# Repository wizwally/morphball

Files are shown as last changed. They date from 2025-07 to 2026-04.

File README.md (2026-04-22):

# 🔮 Metroid Morph Ball

3D printed Metroid Morph Ball action figure with LED animations controlled by ESP32 and IMU motion sensor.





[🇮🇹 Versione Italiana](README.md) | 🇬🇧 English Version

## 📋 Table of Contents

- [Overview](#overview)
- [Features](#features)
- [Hardware](#hardware)
- [Software](#software)
- [Installation](#installation)
- [Usage](#usage)
- [Future Development](#future-development)
- [Contributing](#contributing)
- [License](#license)

## 🎮 Overview

This project recreates the legendary **Morph Ball** from the Metroid series as an interactive 3D printed action figure. The sphere illuminates with 32 programmable WS2812B LEDs and responds to movement thanks to an IMU sensor, automatically entering deep sleep when stationary to save battery.

### Two Available Versions

The project offers two complete implementations:

1. **MicroPython** (`/ESP32` + `/MG24`) - Original standalone version
2. **ESPHome** (`/ESPHome`) - Full Home Assistant integration

## ✨ Features

- 🎨 **32 RGB WS2812B LEDs** with customizable animations
- 🏃 **Motion detection** via LSM6DS3 accelerometer
- 💤 **Automatic deep sleep** for energy saving
- 🔋 **Wake on movement** for instant activation
- 🏠 **Home Assistant integration** (ESPHome version)
- 📱 **WiFi control** with effect selection and configuration
- 🎯 **Custom LED groups** that reproduce the Metroid aesthetic
- ⚡ **Dual-MCU architecture** (ESP32-S3 + MG24) for optimized power consumption

## 🔧 Hardware

### Why Dual-MCU Architecture?

This project uses **two microcontrollers** instead of one for strategic reasons:

1. **🔋 Optimized Power Management**
   - MG24 runs in ultra-low power mode continuously monitoring the IMU
   - ESP32 can deep sleep (~10µA) while MG24 acts as motion "sentinel"
   - Wake-on-motion with minimal latency and maximum battery life

2. **📡 ESP32-S3 Tiny Has No Integrated IMU**
   - The compact ESP32-S3 Tiny form factor doesn't include motion sensors
   - XIAO MG24 has LSM6DS3 accelerometer already integrated on-board
   - No need for external IMU breakout boards and extra wiring

3. **⚡ Task Separation & Real-Time Performance**
   - **MG24**: Dedicated to real-time IMU polling (20Hz) and motion detection
   - **ESP32**: Handles LED animations, WiFi, Home Assistant integration
   - No resource contention - each MCU does what it does best

4. **🎯 Continuous Monitoring Without Impact**
   - MG24 polls IMU continuously at 20Hz without affecting ESP32 performance
   - LED animations run smoothly on ESP32 without IMU polling overhead
   - Clean separation of concerns in the codebase

**Alternative single-MCU approach drawbacks:**
- ❌ ESP32 polling IMU = high power consumption (no true deep sleep)
- ❌ Wake-on-timer = high latency (100-500ms) and still wastes power
- ❌ External IMU module = more complex wiring, larger footprint

**Dual-MCU benefits:**
- ✅ Best-in-class power efficiency (~100µA average in standby)
- ✅ Instant wake on motion (<50ms latency)
- ✅ Modular architecture (can upgrade/swap MCUs independently)
- ✅ Both MCUs in same XIAO form factor (stack back-to-back)

### Main Components

| Component | Model | Quantity | Est. Price | Link/Notes |
|---|---|---|---|---|
| **ESP32-S3 Tiny** | Dual-core, WiFi, BLE | 1 | €8-12 | Ideal small form factor |
| **Seeed XIAO MG24** | ARM Cortex-M33, integrated LSM6DS3 | 1 | €10-15 | Includes on-board IMU |
| **LED Strip WS2812B** | 5V, IP30, 60 LED/m | 32 LED (~53cm) | €5-8 | Cuttable every LED |
| **LiPo Battery** | 3.7V, 500-1000mAh | 1 | €8-12 | Size TBD |
| **Charging Module** | TP4056 or similar | 1 | €2-3 | With protection |
| **ON/OFF Switch** | Slide switch 3 pin | 1 | €0.50 | Miniature |
| **JST Connectors** | 2.54mm pitch | Various | €2-3 | For modular connections |
| **Wires** | AWG 22-26, silicone | 1m | €2-3 | Red/Black/Data |
| **Heat shrink** | Heat shrink tubing | 10cm | €1 | Various sizes |

### Connection Diagram

```
ESP32-S3 Tiny          MG24 (XIAO)         LED Strip
┌─────────────┐       ┌──────────┐        ┌─────────┐
│             │       │          │        │         │
│ GPIO18 ─────┼───────┼──────────┼────────┤ DIN     │
│             │       │          │        │         │
│ GPIO8  ◄────┼───────┤ D4 (OUT) │        │         │
│ (MOTION IN) │       │          │        │         │
│             │       │          │        │         │
│ GPIO7  ─────┼───────► D5 (IN)  │        │         │
│ (ALIVE OUT) │       │ LSM6DS3  │        │         │
│             │       │   IMU    │        │         │
│ 3V3    ─────┼───────┤ 3V3      │        │         │
│ GND    ─────┼───────┤ GND      ├────────┤ GND     │
│             │       │          │        │         │
└─────────────┘       └──────────┘        │ +5V ◄───┤ Battery
                                          └─────────┘
```

### Pin Details

**ESP32-S3 Tiny:**
- `GPIO18`: DIN of WS2812B LED strip
- `GPIO8`: Input from MG24 (HIGH when motion detected)
- `GPIO7`: Output to MG24 (HIGH when animations active)

**MG24 (XIAO):**
- `D4`: Output to ESP32 (pulse on movement)
- `D5`: Input from ESP32 (animation status)
- `D6`: Serial1 TX → ESP32 RX (future UART, structured IMU messages)
- `D7`: Serial1 RX ← ESP32 TX (future UART, configuration commands)
- `D11/D12`: SAMD11 debug bridge — **DO NOT TOUCH**
- `SDA/SCL`: I2C for LSM6DS3 (internal)

### LED Layout

The 32 LEDs are organized in 3 groups to recreate the Metroid aesthetic:

- **Group 0** (6 LEDs): Core grills - Aqua green `(0, 230, 100)`
  - Positions: `[0, 19, 20, 25, 26, 31]`
  
- **Group 1** (12 LEDs): Inner ring - Bright green `(0, 255, 30)`
  - Positions: `[1, 2, 17, 18, 21, 22, 23, 24, 27, 28, 29, 30]`
  
- **Group 2** (14 LEDs): Outer ring - Bright green `(0, 255, 30)`
  - Positions: `[3-16]`

## 💾 Software

### Repository Structure

```
morphball/
├── 3D model/                # 3D printable model
│   └── MorphBall.3mf
├── ESP32/                   # MicroPython standalone version
│   ├── main.py             # Entry point
│   ├── ledstrip.py         # LED management
│   └── animations/         # LED effects
│       ├── base.py
│       ├── pulse.py
│       ├── rotation.py
│       └── static.py
├── MG24/                    # Motion sensor code
│   └── mg24_imu.ino        # Arduino sketch for IMU
├── ESPHome/                 # Home Assistant version
│   ├── morphball.yaml      # ESPHome config
│   ├── README.md           # Setup guide
│   ├── lovelace-card.yaml  # HA Dashboard
│   └── secrets.yaml.example
└── docs/                    # Documentation
    ├── en/                  # English docs
    └── [IT docs]            # Italian docs
```

### MicroPython Version

**Features:**
- Standalone, doesn't require WiFi connection
- Automatic pulse animation
- Sleep after 20 seconds of inactivity
- Deep sleep after additional 20 seconds in standby

**Main files:**
- `main.py`: Main loop, thread management, sleep management
- `ledstrip.py`: Class for WS2812B control with groups
- `animations/`: Modules with different LED effects

### ESPHome Version

**Features:**
- Native Home Assistant integration
- 11 selectable LED effects
- Timeout configuration via dashboard
- OTA updates
- Complete diagnostics (WiFi, uptime, IP)

**Advantages:**
- No mobile app needed
- Configuration via web interface
- HA automations available
- Synchronization with other devices

See [ESPHome/README.md](ESPHome/README.md) for complete details.

## 🚀 Installation

### Software Requirements

**For MicroPython version:**
- Python 3.7+
- `esptool` for flashing
- `mpremote` or `ampy` for file upload

**For ESPHome version:**
- ESPHome CLI or Home Assistant addon
- Home Assistant (obviously!)

### MicroPython Version Setup

1. **Flash MicroPython on ESP32-S3:**
```bash
esptool.py --chip esp32s3 --port /dev/ttyUSB0 erase_flash
esptool.py --chip esp32s3 --port /dev/ttyUSB0 write_flash -z 0x0 esp32s3-micropython.bin
```

2. **Upload code:**
```bash
cd ESP32
mpremote connect /dev/ttyUSB0 cp -r . :
```

3. **Flash MG24:**
```bash
# Use Arduino IDE
# Board: Seeed XIAO MG24
# Upload: MG24/mg24_imu.ino
```

### ESPHome Version Setup

See complete documentation in [ESPHome/README.md](ESPHome/README.md)

**Quick start:**
```bash
cd ESPHome
cp secrets.yaml.example secrets.yaml
# Edit secrets.yaml with your credentials
esphome run morphball.yaml
```

## 🎯 Usage

### MicroPython Version

The Morph Ball activates automatically:
1. **Motion detected** → LEDs turn on with pulse effect
2. **20s of inactivity** → Enters standby (only core grills lit)
3. **Another 20s stationary** → Complete deep sleep
4. **New movement** → Automatic wake and reactivation

### ESPHome Version

**Home Assistant Dashboard:**
1. Turn LEDs on/off
2. Select effect from dropdown
3. Adjust sleep timeout with slider
4. Enable/disable deep sleep mode
5. Monitor motion status and diagnostics

**Example automations:**

```yaml
# Activate Rainbow at sunset
automation:
  - alias: "Morphball Rainbow Sunset"
    trigger:
      platform: sun
      event: sunset
    action:
      - service: select.select_option
        target:
          entity_id: select.metroid_morph_ball_effect
        data:
          option: "Rainbow"
```

## 🔮 Future Development

### Roadmap

- [ ] **Gesture recognition** - Shake, roll, tilt trigger different effects
- [ ] **Battery monitoring** - Charge level indicator
- [ ] **Game mode** - Interactive mini-games
- [ ] **Multi-ball sync** - Multiple Morph Balls communicating
- [ ] **Audio feedback** - Speaker for Metroid sounds
- [ ] **Charging dock** - Wireless charging base
- [ ] **Mobile app** - For standalone MicroPython version
- [ ] **Audio-reactive effects** - Music synchronization

### Contribution Ideas

- New LED animations
- Power consumption optimization
- 3D model improvements
- Porting to other microcontrollers
- Integration with other smart home systems (Alexa, Google Home)

## 🤝 Contributing

Contributions welcome! Here's how:

1. **Fork** the repository
2. Create a **branch** for your feature (`git checkout -b feature/AmazingFeature`)
3. **Commit** your changes (`git commit -m 'Add some AmazingFeature'`)
4. **Push** to the branch (`git push origin feature/AmazingFeature`)
5. Open a **Pull Request**

### Guidelines

- Comment code (English preferred for international collaboration)
- Test changes before committing
- Update documentation if necessary
- Follow existing code style

See [CONTRIBUTING.md](CONTRIBUTING.md) for detailed guidelines.

## 📄 License

This project is released under **GPL-3.0 License**. See [LICENSE](LICENSE) for details.

## 🙏 Acknowledgments

- **Nintendo/Retro Studios** for Metroid inspiration
- **ESPHome Community** for the fantastic framework
- **Home Assistant** for the home automation platform
- **Seeed Studio** for XIAO MG24
- All contributors who will improve this project!

## 📞 Contact

**Gualtiero Saderis** - [@wizwally](https://github.com/wizwally)

Project Link: [https://github.com/wizwally/morphball](https://github.com/wizwally/morphball)

---

## 📚 Documentation

- **English:**
  - [Hardware Guide](docs/en/HARDWARE.md)
  - [Software Architecture](docs/en/SOFTWARE.md)
  - [Build Tutorial](docs/en/TUTORIAL.md)
  - [Contributing Guide](docs/en/CONTRIBUTING.md)

- **Italiano:**
  - [Guida Hardware](docs/HARDWARE.md)
  - [Architettura Software](docs/SOFTWARE.md)
  - [Tutorial Completo](docs/TUTORIAL.md)
  - [Come Contribuire](CONTRIBUTING.md)

---

**Made with ❤️ and nostalgia for Nintendo classics**

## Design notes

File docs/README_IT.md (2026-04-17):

# 🔮 Metroid Morph Ball

3D printed Metroid Morph Ball action figure with LED animations controlled by ESP32 and IMU motion sensor.





🇬🇧 English Version | [🇮🇹 Versione Italiana](docs/README_IT.md)

## 📋 Table of Contents

- [Panoramica](#panoramica)
- [Caratteristiche](#caratteristiche)
- [Hardware](#hardware)
- [Software](#software)
- [Installazione](#installazione)
- [Utilizzo](#utilizzo)
- [Sviluppo Futuro](#sviluppo-futuro)
- [Contribuire](#contribuire)
- [Licenza](#licenza)

## 🎮 Panoramica

Questo progetto ricrea la leggendaria **Morph Ball** della serie Metroid come action figure interattiva stampata in 3D. La sfera si illumina con 32 LED WS2812B programmabili e risponde al movimento grazie a un sensore IMU, entrando automaticamente in deep sleep quando è ferma per risparmiare batteria.

### Due Versioni Disponibili

Il progetto offre due implementazioni complete:

1. **MicroPython** (`/ESP32` + `/MG24`) - Versione standalone originale
2. **ESPHome** (`/ESPHome`) - Integrazione completa con Home Assistant

## ✨ Caratteristiche

- 🎨 **32 LED RGB WS2812B** con animazioni customizzabili
- 🏃 **Rilevamento movimento** tramite accelerometro LSM6DS3
- 💤 **Deep sleep automatico** per risparmio energetico
- 🔋 **Wake su movimento** per attivazione istantanea
- 🏠 **Integrazione Home Assistant** (versione ESPHome)
- 📱 **Controllo WiFi** con selezione effetti e configurazione
- 🎯 **Gruppi LED personalizzati** che riproducono l'estetica Metroid
- ⚡ **Architettura dual-MCU** (ESP32-S3 + MG24) per ottimizzazione consumi

## 🔧 Hardware

### Perché Architettura Dual-MCU?

Questo progetto usa **due microcontrollori** invece di uno per ragioni strategiche:

1. **🔋 Power Management Ottimizzato**
   - MG24 funziona in modalità ultra-low power monitorando continuamente l'IMU
   - ESP32 può andare in deep sleep (~10µA) mentre MG24 fa da "sentinella" per il movimento
   - Wake-on-motion con latenza minima e massima durata batteria

2. **📡 ESP32-S3 Tiny Non Ha IMU Integrato**
   - Il form factor compatto dell'ESP32-S3 Tiny non include sensori di movimento
   - XIAO MG24 ha accelerometro LSM6DS3 già integrato on-board
   - Non servono moduli IMU esterni e cablaggi aggiuntivi

3. **⚡ Separazione Task & Performance Real-Time**
   - **MG24**: Dedicato al polling real-time dell'IMU (20Hz) e rilevamento movimento
   - **ESP32**: Gestisce animazioni LED, WiFi, integrazione Home Assistant
   - Nessuna contesa di risorse - ogni MCU fa ciò per cui è ottimizzato

4. **🎯 Monitoraggio Continuo Senza Impatto**
   - MG24 esegue polling IMU continuo a 20Hz senza impattare performance ESP32
   - Animazioni LED fluide su ESP32 senza overhead polling IMU
   - Separazione pulita delle responsabilità nel codice

**Svantaggi approccio single-MCU:**
- ❌ ESP32 che fa polling IMU = alto consumo (no vero deep sleep)
- ❌ Wake-on-timer = alta latenza (100-500ms) e spreco energia
- ❌ Modulo IMU esterno = cablaggio più complesso, ingombro maggiore

**Vantaggi Dual-MCU:**
- ✅ Massima efficienza energetica (~100µA media in standby)
- ✅ Wake istantaneo su movimento (<50ms latenza)
- ✅ Architettura modulare (upgrade/swap MCU indipendenti)
- ✅ Entrambi MCU in form factor XIAO (stack back-to-back)

### Componenti Principali

| Componente | Modello | Quantità | Note |
|---|---|---|---|
| Microcontroller principale | ESP32-S3 Tiny | 1 | Controllo LED e WiFi |
| Microcontroller IMU | Seeed XIAO MG24 | 1 | Rilevamento movimento |
| LED Strip | WS2812B | 32 LED | Divisi in 3 gruppi |
| IMU | LSM6DS3 | 1 | Integrato nel MG24 |
| Batteria | LiPo 3.7V | 1 | Capacità da definire |
| Switch | ON/OFF | 1 | Alimentazione |

### Schema Connessioni

```
ESP32-S3 Tiny          MG24 (XIAO)         LED Strip
┌─────────────┐       ┌──────────┐        ┌─────────┐
│             │       │          │        │         │
│ GPIO18 ─────┼───────┼──────────┼────────┤ DIN     │
│             │       │          │        │         │
│ GPIO8  ◄────┼───────┤ D4 (OUT) │        │         │
│ (MOTION IN) │       │          │        │         │
│             │       │          │        │         │
│ GPIO7  ─────┼───────► D5 (IN)  │        │         │
│ (ALIVE OUT) │       │ LSM6DS3  │        │         │
│             │       │   IMU    │        │         │
│ 3V3    ─────┼───────┤ 3V3      │        │         │
│ GND    ─────┼───────┤ GND      ├────────┤ GND     │
│             │       │          │        │         │
└─────────────┘       └──────────┘        │ +5V ◄───┤ Batteria
                                          └─────────┘
```

### Dettagli Pin

**ESP32-S3 Tiny:**
- `GPIO18`: DIN del LED strip WS2812B
- `GPIO8`: Input da MG24 (HIGH quando c'è movimento)
- `GPIO7`: Output verso MG24 (HIGH quando animazioni attive)

**MG24 (XIAO):**
- `D4`: Output verso ESP32 (pulse su movimento)
- `D5`: Input da ESP32 (stato animazioni)
- `SDA/SCL`: I2C per LSM6DS3 (interno)

### Disposizione LED

I 32 LED sono organizzati in 3 gruppi per ricreare l'estetica Metroid:

- **Gruppo 0** (6 LED): Core grills - Verde acqua `(0, 230, 100)`
  - Posizioni: `[0, 19, 20, 25, 26, 31]`
  
- **Gruppo 1** (12 LED): Inner ring - Verde brillante `(0, 255, 30)`
  - Posizioni: `[1, 2, 17, 18, 21, 22, 23, 24, 27, 28, 29, 30]`
  
- **Gruppo 2** (14 LED): Outer ring - Verde brillante `(0, 255, 30)`
  - Posizioni: `[3-16]`

## 💾 Software

### Struttura Repository

```
morphball/
├── 3D model/                # Modello 3D stampabile
│   └── MorphBall.3mf
├── ESP32/                   # Versione MicroPython standalone
│   ├── main.py             # Entry point
│   ├── ledstrip.py         # Gestione LED
│   └── animations/         # Effetti LED
│       ├── base.py
│       ├── pulse.py
│       ├── rotation.py
│       └── static.py
├── MG24/                    # Codice sensore movimento
│   └── mg24_imu.ino        # Arduino sketch per IMU
├── ESPHome/                 # Versione Home Assistant
│   ├── morphball.yaml      # Config ESPHome
│   ├── README.md           # Guida setup
│   ├── lovelace-card.yaml  # Dashboard HA
│   └── secrets.yaml.example
└── docs/                    # Documentazione (questa cartella)
```

### Versione MicroPython

**Caratteristiche:**
- Standalone, non richiede connessione WiFi
- Animazione pulse automatica
- Sleep dopo 20 secondi di inattività
- Deep sleep dopo ulteriori 20 secondi in standby

**Files principali:**
- `main.py`: Loop principale, gestione thread, sleep management
- `ledstrip.py`: Classe per controllo WS2812B con gruppi
- `animations/`: Moduli con diversi effetti LED

### Versione ESPHome

**Caratteristiche:**
- Integrazione nativa con Home Assistant
- 11 effetti LED selezionabili
- Configurazione timeout via dashboard
- OTA updates
- Diagnostica completa (WiFi, uptime, IP)

**Vantaggi:**
- Nessuna app mobile necessaria
- Configurazione via interfaccia web
- Automazioni HA disponibili
- Sincronizzazione con altri dispositivi

Vedi [ESPHome/README.md](ESPHome/README.md) per dettagli completi.

## 🚀 Installazione

### Requisiti Software

**Per versione MicroPython:**
- Python 3.7+
- `esptool` per flash
- `mpremote` o `ampy` per upload files

**Per versione ESPHome:**
- ESPHome CLI o addon Home Assistant
- Home Assistant (ovviamente!)

### Setup Versione MicroPython

1. **Flash MicroPython su ESP32-S3:**
```bash
esptool.py --chip esp32s3 --port /dev/ttyUSB0 erase_flash
esptool.py --chip esp32s3 --port /dev/ttyUSB0 write_flash -z 0x0 esp32s3-micropython.bin
```

2. **Upload codice:**
```bash
cd ESP32
mpremote connect /dev/ttyUSB0 cp -r . :
```

3. **Flash MG24:**
```bash
# Usa Arduino IDE
# Board: Seeed XIAO MG24
# Upload: MG24/mg24_imu.ino
```

### Setup Versione ESPHome

Vedi documentazione completa in [ESPHome/README.md](ESPHome/README.md)

**Quick start:**
```bash
cd ESPHome
cp secrets.yaml.example secrets.yaml
# Edita secrets.yaml con le tue credenziali
esphome run morphball.yaml
```

## 🎯 Utilizzo

### Versione MicroPython

La Morph Ball si attiva automaticamente:
1. **Movimento rilevato** → LED si accendono con effetto pulse
2. **20s di inattività** → Entra in standby (solo core grills accesi)
3. **Altri 20s ferma** → Deep sleep completo
4. **Nuovo movimento** → Wake automatico e riattivazione

### Versione ESPHome

**Dashboard Home Assistant:**
1. Accendi/spegni LED
2. Seleziona effetto dal dropdown
3. Regola timeout sleep con slider
4. Abilita/disabilita deep sleep mode
5. Monitora stato movimento e diagnostica

**Automazioni esempio:**

```yaml
# Attiva Rainbow al tramonto
automation:
  - alias: "Morphball Rainbow Sunset"
    trigger:
      platform: sun
      event: sunset
    action:
      - service: select.select_option
        target:
          entity_id: select.metroid_morph_ball_effect
        data:
          option: "Rainbow"
```

## 🔮 Sviluppo Futuro

### Roadmap

- [ ] **Riconoscimento gesti** - Shake, roll, tilt trigger effetti diversi
- [ ] **Batteria monitoring** - Indicatore livello carica
- [ ] **Modalità gioco** - Mini-game interattivi
- [ ] **Sincronizzazione multi-ball** - Più Morph Ball che comunicano
- [ ] **Audio feedback** - Speaker per suoni Metroid
- [ ] **Charging dock** - Base di ricarica wireless
- [ ] **App mobile** - Per versione MicroPython standalone
- [ ] **Effetti audio-reactive** - Sync con musica

### Idee per Contributi

- Nuove animazioni LED
- Ottimizzazione consumi energetici
- Miglioramenti modello 3D
- Porting su altri microcontroller
- Integrazione con altri smart home systems (Alexa, Google Home)

## 🤝 Contribuire

Contributi benvenuti! Ecco come:

1. **Fork** il repository
2. Crea un **branch** per la tua feature (`git checkout -b feature/AmazingFeature`)
3. **Commit** le modifiche (`git commit -m 'Add some AmazingFeature'`)
4. **Push** al branch (`git push origin feature/AmazingFeature`)
5. Apri una **Pull Request**

### Linee Guida

- Commenta il codice (possibilmente in italiano)
- Testa le modifiche prima del commit
- Aggiorna la documentazione se necessario
- Segui lo stile di codice esistente

## 📄 Licenza

Questo progetto è rilasciato sotto licenza **GPL-3.0**. Vedi [LICENSE](LICENSE) per dettagli.

## 🙏 Ringraziamenti

- **Nintendo/Retro Studios** per l'ispirazione Metroid
- **Comunità ESPHome** per il framework fantastico
- **Home Assistant** per la piattaforma domotica
- **Seeed Studio** per il XIAO MG24
- Tutti i contributor che miglioreranno questo progetto!

## 📞 Contatti

**Gualtiero Saderis** - [@wizwally](https://github.com/wizwally)

Project Link: [https://github.com/wizwally/morphball](https://github.com/wizwally/morphball)

---

**Fatto con ❤️ e nostalgia per i classici Nintendo**

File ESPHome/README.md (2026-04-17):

# 🔮 Metroid Morph Ball - ESPHome Edition

Configurazione ESPHome per controllare la Morph Ball via Home Assistant!

## 📋 Hardware Requirements

- **ESP32-S3 Tiny**
- **MG24** con LSM6DS3 IMU (per motion detection)
- **32x WS2812B LEDs**
- Connessioni:
  - GPIO18 → DIN LED strip
  - GPIO8 ← Motion signal dal MG24
  - GPIO7 → Alive signal al MG24

## 🚀 Setup Iniziale

### 1. Preparare secrets.yaml

```bash
cd ESPHome
cp secrets.yaml.example secrets.yaml
nano secrets.yaml  # Edita con le tue credenziali
```

Compila i seguenti campi:
- `wifi_ssid`: Nome della tua rete WiFi
- `wifi_password`: Password WiFi
- `api_key`: Genera con `openssl rand -base64 32`
- `ota_password`: Password per aggiornamenti OTA

### 2. Installare ESPHome

Se non hai ancora ESPHome:

```bash
pip install esphome
```

Oppure usa l'addon di Home Assistant.

### 3. Compilare e Flashare

**Prima volta (via USB):**

```bash
cd ESPHome
esphome run morphball.yaml
```

Seleziona la porta USB dell'ESP32-S3.

**Successivamente (via OTA):**

```bash
esphome run morphball.yaml
# Seleziona l'opzione wireless (morphball.local)
```

### 4. Aggiungere a Home Assistant

1. Vai in **Impostazioni** → **Dispositivi e servizi**
2. Home Assistant dovrebbe rilevare automaticamente il dispositivo
3. Clicca su **Configura** e inserisci l'`api_key` da `secrets.yaml`

### 5. Aggiungere la Dashboard Card

**Opzione A - Con Mushroom Cards (consigliato):**

1. Installa "Mushroom" da HACS
2. Dashboard → Modifica → Aggiungi Card → Manuale
3. Copia il contenuto di `lovelace-card.yaml`

**Opzione B - Senza custom cards:**

1. Dashboard → Modifica → Aggiungi Card → Manuale
2. Copia il contenuto di `lovelace-card-simple.yaml`

## 🎮 Funzionalità

### Controllo LED

11 effetti disponibili:
- **Pulse**: Classico breathing
- **Breathing**: Più lento e smooth
- **Strobe**: Effetto stroboscopico
- **Rainbow**: Arcobaleno scorrevole
- **Color Wipe**: Riempimento a colori
- **Scan**: Scanner tipo K.I.T.T.
- **Twinkle**: Scintillio casuale
- **Fireworks**: Fuochi d'artificio
- **Flicker**: Effetto candela
- **Original Groups**: Animazione originale con 3 gruppi LED

### Sleep Management

- **Sleep Mode**: On/Off per abilitare deep sleep
- **Sleep Timeout**: Tempo di inattività prima dello standby (5-300s)
- **Standby Duration**: Tempo in standby prima del deep sleep (5-120s)

### Motion Detection

Il MG24 rileva movimento tramite IMU e invia segnale all'ESP32:
- Wake automatico dal deep sleep
- Reset del timer di sleep
- Sensore binary_sensor in Home Assistant

## 🔧 Configurazione Avanzata

### Modificare i Colori

Edita il lambda effect "Original Groups" in `morphball.yaml`:

```cpp
// Gruppo 0 - Core grills
Color(R, G, B)  // Modifica questi valori
```

### Aggiungere Nuovi Effetti

Gli effetti ESPHome sono configurabili in `morphball.yaml` sotto `light:` → `effects:`.

Documentazione: https://esphome.io/components/light/index.html#light-effects

### Automazioni Home Assistant

Esempio - Attiva effetto Rainbow al tramonto:

```yaml
automation:
  - alias: "Morphball Rainbow al tramonto"
    trigger:
      - platform: sun
        event: sunset
    action:
      - service: select.select_option
        target:
          entity_id: select.metroid_morph_ball_effect
        data:
          option: "Rainbow"
      - service: light.turn_on
        target:
          entity_id: light.metroid_morph_ball_leds
```

## 🐛 Troubleshooting

### Non si connette al WiFi

1. Controlla `secrets.yaml`
2. L'ESP32 crea un AP fallback: `morphball Fallback`
3. Connettiti e configura WiFi via captive portal

### LED non si accendono

1. Verifica connessione GPIO18 → DIN
2. Controlla alimentazione LED strip (5V, GND)
3. Guarda i log: `esphome logs morphball.yaml`

### Deep sleep non funziona

1. Verifica che Sleep Mode sia ON in Home Assistant
2. Controlla timeout configurati
3. Il movimento continuo previene il deep sleep (corretto!)

### MG24 non invia segnali

1. Verifica connessione GPIO8 ← MG24 D4
2. Controlla che MG24 riceva alimentazione
3. Verifica segnale ALIVE (GPIO7 → MG24 D5)

## 📚 Riferimenti

- [ESPHome Documentation](https://esphome.io)
- [WS2812B Light Effects](https://esphome.io/components/light/index.html#light-effects)
- [Deep Sleep](https://esphome.io/components/deep_sleep.html)
- [Home Assistant ESPHome Integration](https://www.home-assistant.io/integrations/esphome/)

## 🎯 Prossimi Sviluppi

Idee per il futuro:
- [ ] Distinzione tipi di movimento (shake, roll, tilt) sul MG24
- [ ] Effetti LED sincronizzati con musica
- [ ] Integrazione con Alexa/Google Assistant
- [ ] Notifiche push su movimento rilevato
- [ ] Storico attività e statistiche

## 📝 Note

- I gruppi LED originali sono mantenuti nell'effetto "Original Groups"
- Il comportamento di sleep replica il codice MicroPython originale
- Tutte le configurazioni sono persistenti (sopravvivono ai reboot)

---

**Fatto con ❤️ per Home Assistant**

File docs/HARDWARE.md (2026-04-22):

# 🔌 Documentazione Hardware - Metroid Morph Ball

Guida completa all'hardware del progetto Morph Ball.

## 🎯 Razionale Architettura Dual-MCU

### Perché Due Microcontrollori?

Questo design usa **ESP32-S3 + MG24** invece di un singolo MCU per prestazioni e efficienza energetica ottimali:

**🔋 Eccellenza nel Power Management**
- MG24 monitora continuamente l'IMU in modalità ultra-low power (~50µA)
- ESP32 in deep sleep a ~10µA quando inattivo
- **Totale standby: ~100µA** (vs. ~5000µA se ESP32 dovesse fare polling IMU)
- Autonomia batteria in standby: **400+ giorni** vs. ~30 giorni single-MCU

**⚡ Performance Real-Time**
- **MG24**: Polling IMU dedicato a 20Hz, rilevamento movimento <50ms
- **ESP32**: Animazioni LED a 60fps, WiFi, zero overhead interrupt
- Zero contesa risorse = animazioni fluide + wake istantaneo

**🎯 Specializzazione Task**
| Task | ESP32-S3 | MG24 |
|---|---|---|
| Controllo LED | ✅ Primario | - |
| WiFi/BLE | ✅ Primario | - |
| Polling IMU | - | ✅ Primario |
| Rilevamento Movimento | - | ✅ Primario |
| Deep Sleep | ✅ Ultra-basso | ✅ Low power |
| Wake Trigger | Riceve | Invia |

**📐 Integrazione Fisica**
- Entrambi in form factor XIAO (21x17.5mm)
- Stack back-to-back con 4 fili
- Stesso ingombro di un singolo MCU più grande
- Modulare: swap/upgrade indipendenti

**vs. Alternative Single-MCU:**

| Approccio | Consumo (Standby) | Latenza Wake | Complessità |
|---|---|---|---|
| **ESP32 + IMU Esterno** | ~5mA | 100-500ms | Cablaggio complesso |
| **ESP32 wake-on-timer** | ~500µA | 200-1000ms | Media |
| **Dual-MCU (Questo)** | **~100µA** | **<50ms** | Bassa (4 fili) |

## 📦 Bill of Materials (BOM)

### Componenti Elettronici

| Componente | Specifiche | Quantità | Prezzo Est. | Link/Note |
|---|---|---|---|---|
| **ESP32-S3 Tiny** | Dual-core, WiFi, BLE | 1 | €8-12 | Piccolo form factor ideale |
| **Seeed XIAO MG24** | ARM Cortex-M33, LSM6DS3 integrato | 1 | €10-15 | Include IMU on-board |
| **LED Strip WS2812B** | 5V, IP30, 60 LED/m | 32 LED (~53cm) | €5-8 | Tagliabile ogni LED |
| **Batteria LiPo** | 3.7V, 500-1000mAh | 1 | €8-12 | Dimensioni da verificare |
| **Modulo ricarica** | TP4056 o simile | 1 | €2-3 | Con protezione |
| **Switch ON/OFF** | Slide switch 3 pin | 1 | €0.50 | Miniatura |
| **Connettori JST** | 2.54mm pitch | Vari | €2-3 | Per collegamenti modulari |
| **Fili** | AWG 22-26, silicone | 1m | €2-3 | Rosso/Nero/Dati |
| **Heat shrink** | Guaina termorestringente | 10cm | €1 | Varie misure |

### Componenti Meccanici

| Componente | Specifiche | Quantità | Note |
|---|---|---|---|
| **Filamento PETG** | Trasparente/Verde | 100-150g | Per il guscio principale |
| **Filamento PLA/ASA** | Opaco/Nero | 50g | Per supporti interni |
| **Viti M2** | 6-10mm | 4-8 | Fissaggio componenti |
| **Dadi M2** | Standard | 4-8 | O inserti termici |

**Costo totale stimato:** €50-80

## 🔧 Specifiche Tecniche

### ESP32-S3 Tiny

```
MCU: Xtensa® dual-core 32-bit LX7
Clock: fino a 240 MHz
Flash: 4MB
PSRAM: 2MB
WiFi: 802.11 b/g/n
BLE: 5.0
GPIO: 27 disponibili
ADC: 12-bit, 20 canali
Alimentazione: 3.3V (regolatore integrato da 5V)
Dimensioni: 21mm x 17.5mm
```

**Vantaggi:**
- Form factor minuscolo
- WiFi + BLE integrati
- Sufficiente memoria per OTA
- Deep sleep ultra-low power (~10µA)

### Seeed XIAO MG24

```
MCU: Silicon Labs EFR32MG24
Core: ARM Cortex-M33 @ 78 MHz
Flash: 1536 KB
RAM: 256 KB
IMU: LSM6DS3 (I2C integrato)
Alimentazione: 3.3V
Dimensioni: 21mm x 17.5mm (compatibile XIAO)
```

**Vantaggi:**
- LSM6DS3 già integrato (no cablaggio esterno!)
- Ultra low power
- Form factor identico a ESP32-S3
- I2C dedicato per IMU

### WS2812B LED Strip

```
Tipo: RGB LED indirizzabili
Protocollo: WS2812/NeoPixel
Tensione: 5V
Corrente per LED: ~60mA @ bianco full brightness
Corrente 32 LED: ~1.92A @ 100% (raramente necessario)
Frequenza PWM: 800 kHz
Colori: 24-bit (16.7M colori)
```

**Note:**
- Alimentazione 5V, ma DATA a 3.3V funziona (ESP32 out = 3.3V)
- Consigliato condensatore 100-1000µF sulla alimentazione
- Resistenza 330Ω sulla linea DATA (opzionale ma consigliata)

## 🔌 Schema Circuitale Dettagliato

### Connessioni ESP32-S3

```
ESP32-S3 Tiny
┌─────────────────────┐
│                     │
│ 5V  ────────┬───────┼──── Batteria+ (via switch)
│             │       │
│             └───────┼──── LED Strip +5V
│                     │
│ GND ────────┬───────┼──── Batteria-
│             │       │
│             ├───────┼──── LED Strip GND
│             │       │
│             └───────┼──── MG24 GND
│                     │
│ GPIO18 ─────────────┼──── LED Strip DIN
│ (LED_PIN)           │     (opzionale: R 330Ω)
│                     │
│ GPIO8  ◄────────────┼──── MG24 D4 (Motion OUT)
│ (MOTION_PIN)        │
│                     │
│ GPIO7  ─────────────┼──► MG24 D5 (Alive IN)
│ (ALIVE_PIN)         │
│                     │
│ 3V3 ────────────────┼──── MG24 3V3
│                     │
└─────────────────────┘
```

### Connessioni MG24

```
Seeed XIAO MG24
┌──────────────────┐
│                  │
│ 3V3 ◄────────────┼──── ESP32 3V3
│                  │
│ GND ◄────────────┼──── ESP32 GND
│                  │
│ D4  ─────────────┼──► ESP32 GPIO8
│ (PIN_MOTION_OUT) │
│                  │
│ D5  ◄────────────┼──── ESP32 GPIO7
│ (PIN_ALIVE)      │
│                  │
│ D6  ─────────────┼──► ESP32 RX   (Serial1 TX, futura UART)
│ (Serial1 TX)     │
│                  │
│ D7  ◄────────────┼──── ESP32 TX  (Serial1 RX, futura UART)
│ (Serial1 RX)     │
│                  │
│ D11 ─────────────┼──► SAMD11 (bridge debug, NON TOCCARE)
│ D12 ◄────────────┼──── SAMD11 (bridge debug, NON TOCCARE)
│                  │
│ SDA ─────┐       │
│          │ LSM6DS3 (interno)
│ SCL ─────┘       │
│                  │
└──────────────────┘
```

### Logica Segnali

**ALIVE (ESP32 GPIO7 → MG24 D5):**
- `HIGH`: ESP32 sta eseguendo animazioni, MG24 continua a monitorare
- `LOW`: ESP32 in deep sleep, MG24 può andare in low power

**MOTION (MG24 D4 → ESP32 GPIO8):**
- `HIGH` (pulse 200ms): Movimento rilevato (accelerazione > 2.5G)
- `LOW`: Nessun movimento
- Wake pin per deep sleep dell'ESP32

**UART Serial1 (MG24 D6/D7 ↔ ESP32) — riservato, non ancora attivo:**
- `D6` (MG24 TX) → ESP32 RX: messaggi strutturati IMU (tipo gesto + intensità)
- `D7` (MG24 RX) ← ESP32 TX: comandi di configurazione futuri
- Baud rate previsto: 115200
- Vedi sezione BACKLOG in SOFTWARE.md per il protocollo da implementare

**SAMD11 Debug Bridge (D11/D12) — NON TOCCARE:**
- Collegamento interno al chip SAMD11 che gestisce USB/JTAG sul PCB del XIAO
- Riservato esclusivamente al programmatore/debugger della scheda
- Cortocircuiti o scritture su questi pin possono danneggiare il bridge o bloccare il flashing

### Alimentazione

```
Batteria LiPo 3.7V (500-1000mAh)
       │
       ├──► TP4056 (ricarica USB)
       │      │
       │      └──► LED status carica
       │
       └──► Switch ON/OFF
              │
              └──► Boost converter 5V (opzionale)
                   │
                   ├──► ESP32-S3 (ha regolatore 3.3V interno)
                   │
                   └──► LED Strip WS2812B (5V)
```

**Opzioni alimentazione:**

1. **Semplice (consigliato per prototipo):**
   - Batteria → ESP32 diretto (accetta 3.7V su pin 5V)
   - LED a 3.7V (funzionano, meno luminosi)

2. **Boost a 5V (produzione):**
   - Batteria → Boost 5V → ESP32 + LED
   - LED a piena luminosità
   - Boost esempio: MT3608

## 🎨 Layout Fisico 3D

### Disposizione Componenti

```
Vista sezione trasversale:

        ╔════════════════╗  ← Guscio superiore PETG trasparente
        ║   LED Ring     ║  
     ┌──╫────────────────╫──┐
     │  ║  ┌──────────┐  ║  │
     │  ║  │          │  ║  │ ← LED gruppo 2 (ring esterno)
     │  ╠══╪══════════╪══╣  │
     │  ║  │  ESP32   │  ║  │
     │  ║  │   +      │  ║  │ ← LED gruppo 1 (inner)
     │  ║  │  MG24    │  ║  │
     │  ╠══╪══════════╪══╣  │
     │  ║  │          │  ║  │ ← LED gruppo 0 (core grills)
     │  ║  └──────────┘  ║  │
     │  ║                ║  │
     ├──╫────────────────╫──┤
     │  ║    Batteria    ║  │
     │  ║                ║  │
     └──╨────────────────╨──┘
        ╚════════════════╝  ← Guscio inferiore

        [●]  ← Switch ON/OFF
```

### Vincoli Dimensionali

- **Diametro interno:** ~60-80mm (da verificare con modello 3D)
- **Altezza componenti:** max 15mm (stack ESP32+MG24)
- **Spazio batteria:** ~40x30x10mm
- **LED strip:** curvatura raggio min 20mm

## ⚡ Consumi e Autonomia

### Analisi Consumi

**ESP32-S3:**
- Active (WiFi ON, LED ON): ~150-200mA
- Light sleep: ~3-5mA
- Deep sleep: ~10µA

**MG24:**
- Active (IMU polling): ~5-10mA
- Low power: ~50µA

**LED (32x WS2812B):**
- 1 LED @ 100%: ~60mA
- 32 LED @ 100%: ~1920mA (!)
- Tipico (effetto pulse, 50% avg): ~500-800mA

**Totale medio in uso:** ~650-1000mA  
**Totale deep sleep:** ~100µA

### Stima Autonomia

Con batteria **500mAh:**
- Uso continuo (animazioni): ~30-45 minuti
- Standby (solo core): ~2-3 ore
- Deep sleep: ~200+ giorni

Con batteria **1000mAh:**
- Uso continuo: ~1-1.5 ore
- Standby: ~4-6 ore
- Deep sleep: ~400+ giorni

**Raccomandazione:** Batteria 750-1000mAh per bilanciare dimensioni/autonomia.

## 🛠️ Assembly Guide

### Step 1: Preparazione Componenti

1. **Taglia LED strip** a 32 LED
2. **Salda fili** a DIN, 5V, GND
3. **Prepara connettori JST** per modularità
4. **Test LED strip** con Arduino/ESP32 separato

### Step 2: Saldature ESP32-MG24

```
ESP32 GPIO7  ──────► MG24 D5
ESP32 GPIO8  ◄────── MG24 D4
ESP32 3V3    ──────► MG24 3V3
ESP32 GND    ──────► MG24 GND
```

**Consiglio:** Salda ESP32 e MG24 **back-to-back** per risparmiare spazio!

### Step 3: Collegamento LED

1. Salda **DIN** a ESP32 GPIO18 (resistenza 330Ω consigliata)
2. **5V** e **GND** direttamente a batteria (con switch)
3. Condensa tore 470µF tra 5V-GND vicino ai LED

### Step 4: Test Funzionalità

```python
# Test code per ESP32
from machine import Pin
from neopixel import NeoPixel

np = NeoPixel(Pin(18), 32)
np.fill((0, 255, 30))  # Verde
np.write()
```

### Step 5: Montaggio nel Guscio

1. **Posiziona LED** seguendo la guida nel modello 3D
2. **Fissa ESP32+MG24** con viti M2 o hot glue
3. **Inserisci batteria** e modulo ricarica
4. **Routing cavi** pulito e sicuro
5. **Fissa switch** nel foro dedicato

### Step 6: Chiusura e Test Finale

1. **Chiudi guscio** con viti o clip
2. **Test movimento** in tutte le direzioni
3. **Verifica impermeabilità** (se richiesta)
4. **Test autonomia** con timer

## 📏 Design Considerations

### Dissipazione Termica

- ESP32-S3: ~0.5-1W in uso intenso
- LED: ~3-10W a seconda del pattern
- Guscio PETG aiuta dissipazione
- Evitare uso continuativo a >80% luminosità

### Impermeabilità

- Versione base: **NO** (guscio snap-fit)
- Per uso esterno: O-ring nel giunto + sigillante
- Rating possibile: IPX4-IPX5

### Robustezza

- PETG: resistente a cadute da ~1m
- Rinforzi interni consigliati negli angoli di stress
- Peso totale: ~150-200g

## 🔍 Troubleshooting Hardware

### LED non si accendono

- ✓ Verifica alimentazione 5V (multimetro)
- ✓ Controlla continuità DIN, GND
- ✓ Test con singolo LED
- ✓ Verifica polarità LED strip

### ESP32 non si connette

- ✓ Alimentazione stabile 3.3-5V
- ✓ Prova reset button
- ✓ USB cable con data (non solo power!)
- ✓ Driver CP2102/CH340 installati

### MG24 non rileva movimento

- ✓ IMU LSM6DS3 inizializzato (serial monitor)
- ✓ Soglia accelerazione (2.5G default)
- ✓ Connessione I2C funzionante
- ✓ Alimentazione 3.3V stabile

### Consumo eccessivo

- ✓ LED brightness troppo alta
- ✓ WiFi sempre attivo (disattiva se standalone)
- ✓ Polling IMU troppo frequente
- ✓ Deep sleep non si attiva

### Interferenze WiFi

- ✓ LED strip può generare rumore EMI
- ✓ Aggiungi condensatore 100nF vicino ESP32
- ✓ Separa fisicamente LED da antenna WiFi
- ✓ Usa canali WiFi meno affollati

## 📐 Files Gerber/CAD

> TODO: Aggiungere PCB custom (opzionale)
> Per ora: prototipazione su breadboard/perfboard

## 🔗 Riferimenti

- [ESP32-S3 Datasheet](https://www.espressif.com/sites/default/files/documentation/esp32-s3_datasheet_en.pdf)
- [WS2812B Datasheet](https://cdn-shop.adafruit.com/datasheets/WS2812B.pdf)
- [LSM6DS3 Datasheet](https://www.st.com/resource/en/datasheet/lsm6ds3.pdf)
- [XIAO MG24 Wiki](https://wiki.seeedstudio.com/xiao_mg24/)

---

**Ultimo aggiornamento:** Aprile 2026

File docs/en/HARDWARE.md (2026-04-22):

# 🔌 Hardware Documentation - Metroid Morph Ball

Complete hardware guide for the Morph Ball project.

## 🎯 Dual-MCU Architecture Rationale

### Why Two Microcontrollers?

This design uses **ESP32-S3 + MG24** instead of a single MCU for optimal performance and power efficiency:

**🔋 Power Management Excellence**
- MG24 continuously monitors IMU in ultra-low power mode (~50µA)
- ESP32 deep sleeps at ~10µA when inactive
- **Total standby: ~100µA** (vs. ~5000µA if ESP32 had to poll IMU)
- Battery life in standby: **400+ days** vs. ~30 days single-MCU

**⚡ Real-Time Performance**
- **MG24**: Dedicated 20Hz IMU polling, <50ms motion detection
- **ESP32**: 60fps LED animations, WiFi, no interrupt overhead
- Zero resource contention = smooth animations + instant wake

**🎯 Task Specialization**
| Task | ESP32-S3 | MG24 |
|---|---|---|
| LED Control | ✅ Primary | - |
| WiFi/BLE | ✅ Primary | - |
| IMU Polling | - | ✅ Primary |
| Motion Detection | - | ✅ Primary |
| Deep Sleep | ✅ Ultra-low | ✅ Low power |
| Wake Trigger | Receives | Sends |

**📐 Physical Integration**
- Both use XIAO form factor (21x17.5mm)
- Stack back-to-back with 4 wires
- Same footprint as single larger MCU
- Modular: swap/upgrade independently

**vs. Single-MCU Alternatives:**

| Approach | Power (Standby) | Wake Latency | Complexity |
|---|---|---|---|
| **ESP32 + External IMU** | ~5mA | 100-500ms | High wiring |
| **ESP32 wake-on-timer** | ~500µA | 200-1000ms | Medium |
| **Dual-MCU (This)** | **~100µA** | **<50ms** | Low (4 wires) |

## 📦 Bill of Materials (BOM)

### Electronic Components

| Component | Specifications | Qty | Est. Price | Link/Notes |
|---|---|-----|---|---|
| **ESP32-S3 Tiny** | Dual-core, WiFi, BLE | 1 | €8-12 | Ideal small form factor |
| **Seeed XIAO MG24** | ARM Cortex-M33, LSM6DS3 integrated | 1 | €10-15 | Includes on-board IMU |
| **LED Strip WS2812B** | 5V, IP30, 60 LED/m | 32 LED (~53cm) | €5-8 | Cuttable per LED |
| **LiPo Battery** | 3.7V, 500-1000mAh | 1 | €8-12 | Size TBD |
| **Charging Module** | TP4056 or similar | 1 | €2-3 | With protection |
| **ON/OFF Switch** | Slide switch 3 pin | 1 | €0.50 | Miniature |
| **JST Connectors** | 2.54mm pitch | Various | €2-3 | For modular connections |
| **Wires** | AWG 22-26, silicone | 1m | €2-3 | Red/Black/Data |
| **Heat shrink** | Heat shrink tubing | 10cm | €1 | Various sizes |

### Mechanical Components

| Component | Specifications | Qty | Notes |
|---|---|-----|---|
| **PETG Filament** | Transparent/Green | 100-150g | For main shell |
| **PLA/ASA Filament** | Opaque/Black | 50g | For internal supports |
| **M2 Screws** | 6-10mm | 4-8 | Component mounting |
| **M2 Nuts** | Standard | 4-8 | Or heat-set inserts |

**Total estimated cost:** €50-80

## 🔧 Technical Specifications

### ESP32-S3 Tiny

```
MCU: Xtensa® dual-core 32-bit LX7
Clock: up to 240 MHz
Flash: 4MB
PSRAM: 2MB
WiFi: 802.11 b/g/n
BLE: 5.0
GPIO: 27 available
ADC: 12-bit, 20 channels
Power: 3.3V (integrated 5V regulator)
Dimensions: 21mm x 17.5mm
```

**Advantages:**
- Tiny form factor
- Integrated WiFi + BLE
- Sufficient memory for OTA
- Ultra-low power deep sleep (~10µA)

### Seeed XIAO MG24

```
MCU: Silicon Labs EFR32MG24
Core: ARM Cortex-M33 @ 78 MHz
Flash: 1536 KB
RAM: 256 KB
IMU: LSM6DS3 (integrated I2C)
Power: 3.3V
Dimensions: 21mm x 17.5mm (XIAO compatible)
```

**Advantages:**
- LSM6DS3 already integrated (no external wiring!)
- Ultra low power
- Same form factor as ESP32-S3
- Dedicated I2C for IMU

### WS2812B LED Strip

```
Type: Addressable RGB LED
Protocol: WS2812/NeoPixel
Voltage: 5V
Current per LED: ~60mA @ white full brightness
Current 32 LEDs: ~1.92A @ 100% (rarely needed)
PWM Frequency: 800 kHz
Colors: 24-bit (16.7M colors)
```

**Notes:**
- 5V power, but 3.3V DATA works (ESP32 out = 3.3V)
- Recommended 100-1000µF capacitor on power
- 330Ω resistor on DATA line (optional but recommended)

## 🔌 Detailed Circuit Diagram

### ESP32-S3 Connections

```
ESP32-S3 Tiny
┌─────────────────────┐
│                     │
│ 5V  ────────┬───────┼──── Battery+ (via switch)
│             │       │
│             └───────┼──── LED Strip +5V
│                     │
│ GND ────────┬───────┼──── Battery-
│             │       │
│             ├───────┼──── LED Strip GND
│             │       │
│             └───────┼──── MG24 GND
│                     │
│ GPIO18 ─────────────┼──── LED Strip DIN
│ (LED_PIN)           │     (optional: 330Ω R)
│                     │
│ GPIO8  ◄────────────┼──── MG24 D4 (Motion OUT)
│ (MOTION_PIN)        │
│                     │
│ GPIO7  ─────────────┼──► MG24 D5 (Alive IN)
│ (ALIVE_PIN)         │
│                     │
│ 3V3 ────────────────┼──── MG24 3V3
│                     │
└─────────────────────┘
```

### MG24 Connections

```
Seeed XIAO MG24
┌──────────────────┐
│                  │
│ 3V3 ◄────────────┼──── ESP32 3V3
│                  │
│ GND ◄────────────┼──── ESP32 GND
│                  │
│ D4  ─────────────┼──► ESP32 GPIO8
│ (PIN_MOTION_OUT) │
│                  │
│ D5  ◄────────────┼──── ESP32 GPIO7
│ (PIN_ALIVE)      │
│                  │
│ D6  ─────────────┼──► ESP32 RX   (Serial1 TX, future UART)
│ (Serial1 TX)     │
│                  │
│ D7  ◄────────────┼──── ESP32 TX  (Serial1 RX, future UART)
│ (Serial1 RX)     │
│                  │
│ D11 ─────────────┼──► SAMD11 (debug bridge, DO NOT TOUCH)
│ D12 ◄────────────┼──── SAMD11 (debug bridge, DO NOT TOUCH)
│                  │
│ SDA ─────┐       │
│          │ LSM6DS3 (internal)
│ SCL ─────┘       │
│                  │
└──────────────────┘
```

### Signal Logic

**ALIVE (ESP32 GPIO7 → MG24 D5):**
- `HIGH`: ESP32 running animations, MG24 continues monitoring
- `LOW`: ESP32 in deep sleep, MG24 can reduce polling or go low power

**MOTION (MG24 D4 → ESP32 GPIO8):**
- `HIGH` (200ms pulse): Motion detected (acceleration > 2.5G)
- `LOW`: No movement
- Wake pin for ESP32 deep sleep

**UART Serial1 (MG24 D6/D7 ↔ ESP32) — reserved, not yet active:**
- `D6` (MG24 TX) → ESP32 RX: structured IMU messages (gesture type + intensity)
- `D7` (MG24 RX) ← ESP32 TX: future configuration commands
- Target baud rate: 115200
- See BACKLOG section in SOFTWARE.md for the protocol to implement

**SAMD11 Debug Bridge (D11/D12) — DO NOT TOUCH:**
- Internal connection to the SAMD11 chip that handles USB/JTAG on the XIAO PCB
- Reserved exclusively for the board's programmer/debugger
- Short-circuits or writes on these pins can damage the bridge or block flashing

### Power Supply

```
LiPo Battery 3.7V (500-1000mAh)
       │
       ├──► TP4056 (USB charging)
       │      │
       │      └──► LED charge status
       │
       └──► ON/OFF Switch
              │
              └──► 5V Boost converter (optional)
                   │
                   ├──► ESP32-S3 (has internal 3.3V regulator)
                   │
                   └──► LED Strip WS2812B (5V)
```

**Power options:**

1. **Simple (recommended for prototype):**
   - Battery → ESP32 direct (accepts 3.7V on 5V pin)
   - LEDs at 3.7V (work, less bright)

2. **Boost to 5V (production):**
   - Battery → 5V Boost → ESP32 + LEDs
   - LEDs at full brightness
   - Boost example: MT3608

## 🎨 3D Physical Layout

### Component Placement

```
Cross-section view:

        ╔════════════════╗  ← Upper shell PETG transparent
        ║   LED Ring     ║  
     ┌──╫────────────────╫──┐
     │  ║  ┌──────────┐  ║  │
     │  ║  │          │  ║  │ ← LED group 2 (outer ring)
     │  ╠══╪══════════╪══╣  │
     │  ║  │  ESP32   │  ║  │
     │  ║  │   +      │  ║  │ ← LED group 1 (inner)
     │  ║  │  MG24    │  ║  │
     │  ╠══╪══════════╪══╣  │
     │  ║  │          │  ║  │ ← LED group 0 (core grills)
     │  ║  └──────────┘  ║  │
     │  ║                ║  │
     ├──╫────────────────╫──┤
     │  ║    Battery     ║  │
     │  ║                ║  │
     └──╨────────────────╨──┘
        ╚════════════════╝  ← Lower shell

        [●]  ← ON/OFF Switch
```

### Dimensional Constraints

- **Internal diameter:** ~60-80mm (verify with 3D model)
- **Component height:** max 15mm (ESP32+MG24 stack)
- **Battery space:** ~40x30x10mm
- **LED strip:** minimum bend radius 20mm

## ⚡ Power Consumption & Battery Life

### Consumption Analysis

**ESP32-S3:**
- Active (WiFi ON, LEDs ON): ~150-200mA
- Light sleep: ~3-5mA
- Deep sleep: ~10µA

**MG24:**
- Active (IMU polling): ~5-10mA
- Low power: ~50µA

**LEDs (32x WS2812B):**
- 1 LED @ 100%: ~60mA
- 32 LEDs @ 100%: ~1920mA (!)
- Typical (pulse effect, 50% avg): ~500-800mA

**Average total in use:** ~650-1000mA  
**Total deep sleep:** ~100µA

### Battery Life Estimate

With **500mAh** battery:
- Continuous use (animations): ~30-45 minutes
- Standby (core only): ~2-3 hours
- Deep sleep: ~200+ days

With **1000mAh** battery:
- Continuous use: ~1-1.5 hours
- Standby: ~4-6 hours
- Deep sleep: ~400+ days

**Recommendation:** 750-1000mAh battery to balance size/autonomy.

## 🛠️ Assembly Guide

### Step 1: Component Preparation

1. **Cut LED strip** to 32 LEDs
2. **Solder wires** to DIN, 5V, GND
3. **Prepare JST connectors** for modularity
4. **Test LED strip** with separate Arduino/ESP32

### Step 2: ESP32-MG24 Soldering

```
ESP32 GPIO7  ──────► MG24 D5
ESP32 GPIO8  ◄────── MG24 D4
ESP32 3V3    ──────► MG24 3V3
ESP32 GND    ──────► MG24 GND
```

**Tip:** Solder ESP32 and MG24 **back-to-back** to save space!

### Step 3: LED Connection

1. Solder **DIN** to ESP32 GPIO18 (330Ω resistor recommended)
2. **5V** and **GND** directly to battery (with switch)
3. 470µF capacitor between 5V-GND near LEDs

### Step 4: Functionality Test

```python
# Test code for ESP32
from machine import Pin
from neopixel import NeoPixel

np = NeoPixel(Pin(18), 32)
np.fill((0, 255, 30))  # Green
np.write()
```

### Step 5: Shell Mounting

1. **Position LEDs** following 3D model guide
2. **Secure ESP32+MG24** with M2 screws or hot glue
3. **Insert battery** and charging module
4. **Clean cable routing** and secure
5. **Mount switch** in dedicated hole

### Step 6: Final Closure & Test

1. **Close shell** with screws or clips
2. **Motion test** in all directions
3. **Verify waterproofing** (if required)
4. **Battery life test** with timer

## 🔍 Hardware Troubleshooting

### LEDs don't light up

- ✓ Verify 5V power (multimeter)
- ✓ Check DIN signal continuity
- ✓ Test with single LED
- ✓ Verify LED strip polarity

### ESP32 won't connect

- ✓ Stable 3.3-5V power
- ✓ Try reset button
- ✓ USB cable with data (not just power!)
- ✓ CP2102/CH340 drivers installed

### MG24 doesn't detect motion

- ✓ IMU LSM6DS3 initialized (serial monitor)
- ✓ Acceleration threshold (2.5G default)
- ✓ I2C connection working
- ✓ Stable 3.3V power

### Excessive consumption

- ✓ LED brightness too high
- ✓ WiFi always active (disable if standalone)
- ✓ IMU polling too frequent
- ✓ Deep sleep not activating

### WiFi interference

- ✓ LED strip can generate EMI noise
- ✓ Add 100nF capacitor near ESP32
- ✓ Physically separate LEDs from WiFi antenna
- ✓ Use less crowded WiFi channels

## 🔗 References

- [ESP32-S3 Datasheet](https://www.espressif.com/sites/default/files/documentation/esp32-s3_datasheet_en.pdf)
- [WS2812B Datasheet](https://cdn-shop.adafruit.com/datasheets/WS2812B.pdf)
- [LSM6DS3 Datasheet](https://www.st.com/resource/en/datasheet/lsm6ds3.pdf)
- [XIAO MG24 Wiki](https://wiki.seeedstudio.com/xiao_mg24/)

---

**Last updated:** April 2026

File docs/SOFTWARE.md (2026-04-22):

# 💻 Architettura Software - Metroid Morph Ball

Guida completa all'architettura software del progetto.

## 📊 Panoramica Architettura

```
┌─────────────────────────────────────────────┐
│           HOME ASSISTANT (opzionale)        │
│  ┌────────────────────────────────────┐    │
│  │  Dashboard Lovelace                │    │
│  │  - Controllo LED                   │    │
│  │  - Selezione effetti               │    │
│  │  - Config sleep                    │    │
│  └────────────────────────────────────┘    │
│                    │                        │
│                    │ WiFi / API             │
└────────────────────┼────────────────────────┘
                     │
                     ▼
┌─────────────────────────────────────────────┐
│              ESP32-S3 TINY                   │
│  ┌──────────────────────────────────────┐  │
│  │  VERSIONE A: MicroPython             │  │
│  │  - main.py (event loop, threads)     │  │
│  │  - ledstrip.py (WS2812B driver)      │  │
│  │  - animations/* (effects)            │  │
│  └──────────────────────────────────────┘  │
│               OR                            │
│  ┌──────────────────────────────────────┐  │
│  │  VERSIONE B: ESPHome                 │  │
│  │  - morphball.yaml (config)           │  │
│  │  - Built-in effects library          │  │
│  │  - OTA updates                       │  │
│  └──────────────────────────────────────┘  │
│                                             │
│  GPIO Management:                           │
│  - GPIO18 → LED Strip DIN                  │
│  - GPIO8  ← Motion signal (wake pin)       │
│  - GPIO7  → Alive signal                   │
└───────┬─────────────────────────┬───────────┘
        │                         │
        │ WS2812 Protocol         │ Digital I/O
        ▼                         ▼
┌───────────────┐         ┌──────────────────┐
│  LED STRIP    │         │  SEEED MG24      │
│  32x WS2812B  │         │                  │
│               │         │  - mg24_imu.ino  │
│  3 Groups:    │         │  - LSM6DS3 IMU   │
│  - Core (6)   │         │  - Motion detect │
│  - Inner (12) │         │                  │
│  - Ring (14)  │         │  Acceleration    │
└───────────────┘         │  threshold: 2.5G │
                          └──────────────────┘
```

## 🐍 Versione MicroPython

### Architettura Multi-Thread

```python
# Thread Model

Main Thread (REPL)
    │
    ├─► Animation Thread
    │   │
    │   └─► while active:
    │           leds.pulse()
    │           fade_in/out()
    │
    └─► Motion Monitor Thread
        │
        └─► while True:
                check_timeout()
                sleep_management()
                deep_sleep()
```

### File: main.py

**Responsabilità:**
- Setup iniziale GPIO
- Gestione interrupt motion sensor
- Coordinamento thread
- Sleep state machine

**Componenti chiave:**

```python
# State globals
active = True                    # Animazione attiva/standby
last_motion_time = ticks_ms()   # Timestamp ultimo movimento
anim_thread_started = False     # Flag thread animazione

# Hardware setup
alive_pin = Pin(ALIVE_PIN, Pin.OUT)
motion_pin = Pin(MOTION_PIN, Pin.IN)
leds = LEDStrip(LED_PIN, NUM_LEDS, GROUPS)

# ISR - Interrupt Service Routine
def motion_interrupt(pin):
    """
    Chiamata su RISING edge di motion_pin.
    Wake da standby se necessario.
    """
    global last_motion_time, active
    last_motion_time = time.ticks_ms()
    if not active:
        active = True
        start_animation_thread()

# Thread functions
def animation_loop():
    """Esegue animazioni LED in loop"""
    
def motion_monitor():
    """Monitora timeout e gestisce sleep"""
```

**State Machine:**

```
┌─────────┐  movimento   ┌────────────┐
│  ACTIVE │ ◄────────────┤   STANDBY  │
│         │              │            │
│ LED ON  │              │ Core only  │
└────┬────┘              └─────┬──────┘
     │                         │
     │ timeout 20s            │ timeout 20s
     │                         │
     ▼                         ▼
┌────────────┐          ┌─────────────┐
│  STANDBY   │          │ DEEP SLEEP  │
│            │          │             │
│ Core fade  │          │ Wake on GPIO│
└────────────┘          └─────────────┘
```

### File: ledstrip.py

**Classe principale:**

```python
class LEDStrip:
    def __init__(self, pin, num_leds, groups):
        self.np = NeoPixel(Pin(pin), num_leds)
        self.groups = groups
        self.num_leds = num_leds
    
    # Metodi per gruppi
    def set_group_color(self, group_id, color)
    def clear_group(self, group_id)
    
    # Animazioni base
    def pulse(self, duration=1)
    def fade_in(self, duration=1, group_id=None)
    def fade_out(self, duration=1, group_id=None)
    
    # Utility
    def clear()
    def show()
```

**Design pattern:**
- Astrazione gruppi LED (nasconde mapping fisico)
- Animazioni non-blocking (controllo durata via parametri)
- Thread-safe (importante per multi-threading)

### File: animations/

Directory con moduli animazioni:

**base.py** - Classe base astratta:
```python
class Animation:
    def __init__(self, ledstrip):
        self.ledstrip = ledstrip
    
    def run(self):
        """Override in subclass"""
        pass
```

**pulse.py** - Breathing effect:
```python
class PulseAnimation(Animation):
    def run(self, duration=1):
        # Fade in/out sinusoidale
```

**rotation.py** - Effetto rotazione:
```python
class RotationAnimation(Animation):
    def run(self, speed=50):
        # Shift circolare dei colori
```

**static.py** - Colori fissi:
```python
class StaticAnimation(Animation):
    def run(self, colors):
        # Set e hold
```

### Deep Sleep & Wake

```python
# Setup wake pin
esp32.wake_on_ext1(
    pins=(Pin(MOTION_PIN),), 
    level=esp32.WAKEUP_ANY_HIGH
)

# Entrare in deep sleep
machine.deepsleep()

# All'uscita dal deep sleep:
# - ESP32 fa RESET completo
# - main.py riparte da capo
# - Stato non persistente (RAM azzerata)
```

**Wake flow:**

```
MG24 rileva movimento
    │
    └─► GPIO8 = HIGH (200ms pulse)
         │
         └─► ESP32 wake
              │
              └─► Boot sequence
                   │
                   └─► main.py restart
                        │
                        └─► alive_pin.on()
                             │
                             └─► Animazione avviata
```

## 🏠 Versione ESPHome

### Architettura Event-Driven

ESPHome usa un'architettura basata su **componenti** e **automazioni**.

```yaml
# Struttura concettuale

esphome:
  on_boot: [actions]

binary_sensor:        # Input events
  on_press: [actions]
  on_release: [actions]

light:                # Output control
  effects: [...]

interval:             # Periodic tasks
  - interval: 1s
    then: [actions]

script:               # Reusable actions
  - id: script_name
    then: [actions]
```

### File: morphball.yaml

**Sezioni principali:**

#### 1. Configurazione Base

```yaml
substitutions:
  device_name: morphball
  friendly_name: "Metroid Morph Ball"

esp32:
  board: esp32-s3-devkitc-1
  framework:
    type: arduino

wifi:
  ssid: !secret wifi_ssid
  password: !secret wifi_password
```

#### 2. GPIO Setup

```yaml
# Output ALIVE
output:
  - platform: gpio
    pin: GPIO7
    id: alive_output

# Input MOTION
binary_sensor:
  - platform: gpio
    pin: GPIO8
    id: motion_sensor
    on_press:
      - script.execute: reset_sleep_timer
      - if: [wake logic]
```

#### 3. LED Control

```yaml
light:
  - platform: neopixelbus
    pin: GPIO18
    num_leds: 32
    id: morphball_light
    effects:
      - pulse:
          name: "Pulse"
      - addressable_lambda:
          name: "Custom"
          lambda: |-
            // C++ code qui
```

**Lambda Effects - Dettaglio:**

```cpp
// Lambda effect con accesso diretto ai LED

it[index] = Color(R, G, B);

// Variabili static per stato persistente
static float brightness = 0.5;
static uint32_t last_update = 0;

// Logic
if (millis() - last_update > interval) {
    // Update colors
}
```

#### 4. Sleep Management

```yaml
globals:
  - id: last_motion_time
    type: uint32_t
  - id: sleep_mode_enabled
    type: bool

interval:
  - interval: 1s
    then:
      - if:
          condition:
            lambda: 'return check_timeout();'
          then:
            - light.turn_off
            - delay
            - deep_sleep.enter
```

#### 5. Home Assistant Integration

```yaml
api:
  encryption:
    key: !secret api_key

# Entità esposte automaticamente:
# - light.morphball_light
# - select.morphball_effect
# - number.morphball_sleep_timeout
# - binary_sensor.morphball_motion
# - sensor.morphball_wifi_signal
```

### Component Lifecycle

```
Boot
 │
 ├─► on_boot actions
 │    └─► alive_pin.on()
 │         light.turn_on()
 │
 ├─► Setup loops
 │    └─► interval timers start
 │
 └─► Main loop
      │
      ├─► WiFi management
      ├─► API communication
      ├─► Component updates
      └─► Event handling
           │
           ├─► binary_sensor triggers
           ├─► light effect updates
           └─► interval callbacks
```

### OTA Updates

```yaml
ota:
  platform: esphome
  password: !secret ota_password

# Workflow:
# 1. esphome run morphball.yaml --device morphball.local
# 2. Compila nuovo firmware
# 3. Upload via WiFi (no cable!)
# 4. Auto-reboot
```

## 🤖 MG24 - Motion Detection

### File: mg24_imu.ino

**Architettura:**

```cpp
// Setup
void setup() {
    pinMode(PIN_ALIVE, INPUT);
    pinMode(PIN_MOTION_OUT, OUTPUT);
    IMU.begin();
}

// Loop
void loop() {
    // 1. Leggi stato ESP32
    check_alive_signal();
    
    // 2. Leggi IMU
    aX = IMU.readFloatAccelX();
    aY = IMU.readFloatAccelY();
    aZ = IMU.readFloatAccelZ();
    
    // 3. Calcola magnitude
    aSum = abs(aX) + abs(aY) + abs(aZ);
    
    // 4. Threshold check
    if (aSum >= 2.5) {
        pulse_motion_pin();
    }
    
    delay(50);  // 20 Hz polling
}
```

**Detection Algorithm:**

```cpp
// Somma delle accelerazioni assolute
float aSum = fabs(aX) + fabs(aY) + fabs(aZ);

// Threshold statico
const float threshold = 2.5;  // G

// Debouncing temporale
static unsigned long lastMove = 0;
if (millis() - lastMove > 200) {  // Min 200ms tra pulse
    digitalWrite(PIN_MOTION_OUT, HIGH);
    lastMove = millis();
}
```

**Possibili Miglioramenti:**

```cpp
// 1. Riconoscimento gesti
enum Gesture {
    SHAKE,      // Oscillazione rapida
    ROLL,       // Rotazione continua
    TILT,       // Inclinazione statica
    TAP,        // Colpo singolo
    DOUBLE_TAP  // Doppio colpo
};

// 2. Soglia adattativa
float adaptive_threshold = 
    baseline_noise * 1.5 + offset;

// 3. Comunicazione I2C/UART invece di GPIO
// Inviare tipo di gesto + intensità
```

## 🔄 Comunicazione Inter-MCU

### Protocollo GPIO Attuale

**Segnale ALIVE (ESP32 → MG24):**

```
HIGH (3.3V)
  │     ┌───────────────────────┐
  │     │  Animazioni attive    │
  │     │  MG24 polling normale │
  │     └───────────────────────┘
  │
  └─► LOW (0V)
        │  ESP32 in deep sleep
        │  MG24 può ridurre polling
        │  o andare in low power
        └───────────────────────┘
```

**Segnale MOTION (MG24 → ESP32):**

```
Movimento rilevato
  │
  ├─► Pulse HIGH (200ms)
  │    │
  │    └─► ESP32 wake (se in deep sleep)
  │         o reset timeout (se attivo)
  │
  └─► Return LOW
```

### Protocolli Alternativi (Future)

#### Opzione A: UART

```cpp
// MG24 invia
Serial.write('S');  // Shake
Serial.write('R');  // Roll
Serial.write('T');  // Tilt

// ESP32 riceve
char gesture = Serial.read();
switch(gesture) {
    case 'S': trigger_shake_effect(); break;
    // ...
}
```

#### Opzione B: I2C

```cpp
// MG24 come slave I2C
#define MG24_I2C_ADDR 0x42

// ESP32 read
Wire.requestFrom(MG24_I2C_ADDR, 2);
uint8_t gesture = Wire.read();
uint8_t intensity = Wire.read();
```

#### Opzione C: Multiple GPIO

```cpp
// 3 GPIO per 8 combinazioni
GPIO_BIT0 = shake_detected;
GPIO_BIT1 = roll_detected;
GPIO_BIT2 = tap_detected;

// ESP32 read as 3-bit value
uint8_t gesture = (bit2 << 2) | (bit1 << 1) | bit0;
```

## 📊 Performance & Optimization

### Timing Analysis

**MicroPython:**
```
Animation frame time: ~20-50ms
Thread context switch: ~1-5ms
GPIO interrupt latency: <1ms
Deep sleep current: ~10µA
Wake time: ~100-300ms
```

**ESPHome:**
```
Effect update: 16-50ms (configurable)
API response: <100ms (LAN)
OTA update: ~30-60s
Component loop: 16ms (60 Hz)
```

### Memory Usage

**MicroPython ESP32-S3:**
```
Firmware: ~1.5MB flash
User code: ~50KB
Runtime RAM: ~100KB
Free heap: ~150KB
```

**ESPHome ESP32-S3:**
```
Firmware: ~2MB flash
Config embedded: ~10KB
Runtime: ~150KB
OTA partition: ~2MB
```

### Ottimizzazioni

#### LED Performance

```python
# ❌ Lento - aggiorna ogni LED
for i in range(32):
    np[i] = color
    np.write()  # 32 write() calls!

# ✅ Veloce - batch update
for i in range(32):
    np[i] = color
np.write()  # 1 write() call
```

#### Sleep Aggressiveness

```python
# Risparmio energia - riduci polling

# ❌ CPU busy
while True:
    check_something()
    # No delay!

# ✅ CPU sleep tra check
while True:
    check_something()
    time.sleep_ms(100)  # 90% CPU idle
```

## 🧪 Testing & Debug

### MicroPython REPL

```python
# Connetti via USB
screen /dev/ttyUSB0 115200

# Test interattivo
>>> from ledstrip import LEDStrip
>>> leds = LEDStrip(18, 32, GROUPS)
>>> leds.set_group_color(0, (255, 0, 0))
>>> leds.show()
```

### ESPHome Logs

```bash
# Monitor live
esphome logs morphball.yaml

# Log levels
logger:
  level: DEBUG  # VERBOSE, DEBUG, INFO, WARN, ERROR
  
# Custom log
ESP_LOGD("tag", "Motion: %d", value);
```

### Debug GPIO

```python
# Oscilloscopio software
from machine import Pin, time_pulse_us

pin = Pin(8, Pin.IN)
duration = time_pulse_us(pin, 1)  # Misura HIGH pulse
print(f"Pulse: {duration}µs")
```

## 📚 API Reference

### MicroPython LEDStrip API

```python
class LEDStrip:
    def __init__(self, pin: int, num_leds: int, 
                 groups: dict)
    
    def set_group_color(self, group_id: int, 
                       color: tuple[int, int, int])
    
    def pulse(self, duration: float = 1.0)
    
    def fade_in(self, duration: float = 1.0, 
                group_id: int = None)
    
    def fade_out(self, duration: float = 1.0, 
                 group_id: int = None)
    
    def clear(self, group_id: int = None)
    
    def show(self)
```

### ESPHome Services

```yaml
# Chiamabile da HA automations

service: light.turn_on
target:
  entity_id: light.morphball_light
data:
  effect: "Rainbow"
  brightness: 200

service: select.select_option
target:
  entity_id: select.morphball_effect
data:
  option: "Pulse"
```

## 🔗 Riferimenti Esterni

- [MicroPython Docs](https://docs.micropython.org/)
- [ESPHome Docs](https://esphome.io/)
- [NeoPixel Guide](https://learn.adafruit.com/adafruit-neopixel-uberguide)
- [ESP32-S3 Technical Reference](https://www.espressif.com/sites/default/files/documentation/esp32-s3_technical_reference_manual_en.pdf)

---

## 📋 BACKLOG — Lavoro UART da Fare

Questa sezione traccia il lavoro pianificato per sostituire il protocollo GPIO binario (MOTION/ALIVE) con una comunicazione UART strutturata su **MG24 D6 (TX) / D7 (RX)** ↔ **ESP32 Serial1**.

---

### [ ] 1. Definire il protocollo messaggi strutturati MG24 → ESP32

Il protocollo deve essere leggero (adatto a 115200 baud, nessun allocator dinamico sul MG24) e facilmente decodificabile in MicroPython.

**Formato proposto — frame binario fisso 4 byte:**

```
┌────────┬────────┬────────┬────────┐
│  0xAA  │  TYPE  │ INTENS │  0x55  │
│ (sync) │ (gesto)│ (0-255)│ (end)  │
└────────┴────────┴────────┴────────┘
```

| Campo | Valore | Descrizione |
|---|---|---|
| `0xAA` | sync byte | Marker di inizio frame |
| `TYPE` | enum 1 byte | Tipo movimento (vedi tabella sotto) |
| `INTENS` | 0–255 | Intensità normalizzata (0 = minimo, 255 = massimo) |
| `0x55` | end byte | Marker di fine frame (sanity check) |

**Tipi di movimento (`TYPE`):**

| Valore | Nome | Trigger |
|---|---|---|
| `0x01` | `MOTION` | Movimento generico (rimpiazza GPIO pulse) |
| `0x02` | `SHAKE` | Oscillazione rapida su ≥2 assi |
| `0x03` | `ROLL` | Rotazione continua (aSum > soglia per >500ms) |
| `0x04` | `TAP` | Picco singolo breve (< 100ms) |
| `0x05` | `DOUBLE_TAP`  | Due picchi entro 300ms |
| `0x06` | `TILT` | Inclinazione statica (asse Z fuori range)  |
| `0xFF` | `HEARTBEAT` | Keep-alive ogni 2s (nessun movimento) |

---

### [ ] 2. Encoder lato Arduino (MG24 — `mg24_imu.ino`)

Modifiche al loop Arduino per inviare frame UART invece di (o in aggiunta a) il pulse GPIO:

```cpp
// Aggiungi a mg24_imu.ino

#define UART_BAUD   115200
#define FRAME_SYNC  0xAA
#define FRAME_END   0x55

// Enum tipi gesto
enum GestureType : uint8_t {
  MOTION     = 0x01,
  SHAKE      = 0x02,
  ROLL       = 0x03,
  TAP        = 0x04,
  DOUBLE_TAP = 0x05,
  TILT       = 0x06,
  HEARTBEAT  = 0xFF,
};

void sendGestureFrame(GestureType type, uint8_t intensity) {
  Serial1.write(FRAME_SYNC);
  Serial1.write((uint8_t)type);
  Serial1.write(intensity);
  Serial1.write(FRAME_END);
}

// Nel setup():
//   Serial1.begin(UART_BAUD);  // D6=TX, D7=RX

// Nel loop(), sostituire il pulse GPIO con:
//   uint8_t intensity = (uint8_t)constrain(map(aSum * 100, 0, 500, 0, 255), 0, 255);
//   sendGestureFrame(MOTION, intensity);
//   (mantenere anche il GPIO D4 per compatibilità con deep-sleep wake)

// Heartbeat separato ogni 2s:
//   static unsigned long lastHeartbeat = 0;
//   if (millis() - lastHeartbeat > 2000) {
//     sendGestureFrame(HEARTBEAT, 0);
//     lastHeartbeat = millis();
//   }
```

**Note implementative:**
- `Serial1` su XIAO MG24 usa fisicamente `D6` (TX) e `D7` (RX) — verificare pinout con `Serial1.begin()` nella libreria Seeed
- Mantenere il pulse su `D4` (GPIO) per continuare a fare wake dall'ESP32 deep sleep (il UART non può wakeup da deep sleep senza hardware UART wakeup)
- `intensity` = `aSum` scalata su 0–255 (`map(aSum, 0, 5.0, 0, 255)`)

---

### [ ] 3. Decoder lato MicroPython (ESP32 — `ESP32/main.py`)

Aggiungere un thread o ISR che legge i frame UART e aggiorna lo stato delle animazioni:

```python
# Aggiungere in main.py o in un nuovo file uart_receiver.py

from machine import UART
import struct

UART_BAUD     = 115200
FRAME_SYNC    = 0xAA
FRAME_END     = 0x55
FRAME_LEN     = 4

GESTURE_NAMES = {
    0x01: "MOTION",
    0x02: "SHAKE",
    0x03: "ROLL",
    0x04: "TAP",
    0x05: "DOUBLE_TAP",
    0x06: "TILT",
    0xFF: "HEARTBEAT",
}

# Inizializzazione (scegliere i pin UART corretti per ESP32-S3 Tiny)
uart = UART(1, baudrate=UART_BAUD, tx=PIN_UART_TX, rx=PIN_UART_RX)

def read_gesture_frame():
    """
    Legge un frame da 4 byte. Ritorna (gesture_type, intensity) o None.
    Cerca il sync byte 0xAA per risincronizzarsi in caso di rumore.
    """
    while uart.any():
        b = uart.read(1)[0]
        if b != FRAME_SYNC:
            continue
        rest = uart.read(3)
        if len(rest) < 3 or rest[2] != FRAME_END:
            continue
        return rest[0], rest[1]   # (type, intensity)
    return None

def uart_monitor_loop():
    """Thread che processa i frame UART e aggiorna lo stato globale."""
    global last_motion_time, active, current_gesture
    while True:
        frame = read_gesture_frame()
        if frame:
            gesture_type, intensity = frame
            if gesture_type != 0xFF:   # ignora heartbeat
                last_motion_time = time.ticks_ms()
                current_gesture = gesture_type
                # TODO: mappare tipo gesto → animazione specifica
                #   0x02 SHAKE  → effetto "esplosione" rapido
                #   0x03 ROLL   → effetto rotazione
                #   0x04 TAP    → flash singolo
        time.sleep_ms(10)
```

**Note implementative:**
- Identificare i pin UART1 fisici sull'ESP32-S3 Tiny (controllare lo schema della board)
- Il frame sync `0xAA` + end `0x55` permette di risincronizzarsi senza buffer circolare complesso
- Il `HEARTBEAT` serve a rilevare se il MG24 si è bloccato (assenza per >5s = errore)
- Fase successiva: mappare `current_gesture` a effetti animazione diversi in `animations/`

---

### [ ] 4. Mapping gesti → animazioni (fase successiva)

Dopo aver validato il canale UART, collegare i tipi di gesto alle animazioni:

| Gesto | Animazione LED suggerita |
|---|---|
| `MOTION` | Comportamento attuale (pulse verde) |
| `SHAKE` | Flash bianco rapido + burst intensità |
| `ROLL` | `RotationAnimation` con velocità proporzionale a `intensity` |
| `TAP` | Singolo flash del gruppo core (group 0) |
| `DOUBLE_TAP`  | Cambio effetto ciclico |
| `TILT` | Colore base cambia (verde → ciano → blu) in base all'asse |

---

**Ultimo aggiornamento:** Aprile 2026

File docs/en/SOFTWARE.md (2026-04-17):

# 💻 Software Architecture - Metroid Morph Ball

Complete guide to the project's software architecture.

## 📊 Architecture Overview

```
┌─────────────────────────────────────────────┐
│           HOME ASSISTANT (optional)         │
│  ┌────────────────────────────────────┐    │
│  │  Lovelace Dashboard                │    │
│  │  - LED Control                     │    │
│  │  - Effect selection                │    │
│  │  - Sleep config                    │    │
│  └────────────────────────────────────┘    │
│                    │                        │
│                    │ WiFi / API             │
└────────────────────┼────────────────────────┘
                     │
                     ▼
┌─────────────────────────────────────────────┐
│              ESP32-S3 TINY                   │
│  ┌──────────────────────────────────────┐  │
│  │  VERSION A: MicroPython              │  │
│  │  - main.py (event loop, threads)     │  │
│  │  - ledstrip.py (WS2812B driver)      │  │
│  │  - animations/* (effects)            │  │
│  └──────────────────────────────────────┘  │
│               OR                            │
│  ┌──────────────────────────────────────┐  │
│  │  VERSION B: ESPHome                  │  │
│  │  - morphball.yaml (config)           │  │
│  │  - Built-in effects library          │  │
│  │  - OTA updates                       │  │
│  └──────────────────────────────────────┘  │
│                                             │
│  GPIO Management:                           │
│  - GPIO18 → LED Strip DIN                  │
│  - GPIO8  ← Motion signal (wake pin)       │
│  - GPIO7  → Alive signal                   │
└───────┬─────────────────────────┬───────────┘
        │                         │
        │ WS2812 Protocol         │ Digital I/O
        ▼                         ▼
┌───────────────┐         ┌──────────────────┐
│  LED STRIP    │         │  SEEED MG24      │
│  32x WS2812B  │         │                  │
│               │         │  - mg24_imu.ino  │
│  3 Groups:    │         │  - LSM6DS3 IMU   │
│  - Core (6)   │         │  - Motion detect │
│  - Inner (12) │         │                  │
│  - Ring (14)  │         │  Acceleration    │
└───────────────┘         │  threshold: 2.5G │
                          └──────────────────┘
```

## 🐍 MicroPython Version

### Multi-Thread Architecture

```python
# Thread Model

Main Thread (REPL)
    │
    ├─► Animation Thread
    │   │
    │   └─► while active:
    │           leds.pulse()
    │           fade_in/out()
    │
    └─► Motion Monitor Thread
        │
        └─► while True:
                check_timeout()
                sleep_management()
                deep_sleep()
```

### File: main.py

**Responsibilities:**
- Initial GPIO setup
- Motion sensor interrupt management
- Thread coordination
- Sleep state machine

**Key components:**

```python
# State globals
active = True                    # Animation active/standby
last_motion_time = ticks_ms()   # Last movement timestamp
anim_thread_started = False     # Animation thread flag

# Hardware setup
alive_pin = Pin(ALIVE_PIN, Pin.OUT)
motion_pin = Pin(MOTION_PIN, Pin.IN)
leds = LEDStrip(LED_PIN, NUM_LEDS, GROUPS)

# ISR - Interrupt Service Routine
def motion_interrupt(pin):
    """
    Called on RISING edge of motion_pin.
    Wake from standby if necessary.
    """
    global last_motion_time, active
    last_motion_time = time.ticks_ms()
    if not active:
        active = True
        start_animation_thread()

# Thread functions
def animation_loop():
    """Executes LED animations in loop"""
    
def motion_monitor():
    """Monitors timeout and manages sleep"""
```

**State Machine:**

```
┌─────────┐  movement    ┌────────────┐
│  ACTIVE │ ◄────────────┤   STANDBY  │
│         │              │            │
│ LED ON  │              │ Core only  │
└────┬────┘              └─────┬──────┘
     │                         │
     │ timeout 20s            │ timeout 20s
     │                         │
     ▼                         ▼
┌────────────┐          ┌─────────────┐
│  STANDBY   │          │ DEEP SLEEP  │
│            │          │             │
│ Core fade  │          │ Wake on GPIO│
└────────────┘          └─────────────┘
```

### File: ledstrip.py

**Main class:**

```python
class LEDStrip:
    def __init__(self, pin, num_leds, groups):
        self.np = NeoPixel(Pin(pin), num_leds)
        self.groups = groups
        self.num_leds = num_leds
    
    # Group methods
    def set_group_color(self, group_id, color)
    def clear_group(self, group_id)
    
    # Base animations
    def pulse(self, duration=1)
    def fade_in(self, duration=1, group_id=None)
    def fade_out(self, duration=1, group_id=None)
    
    # Utility
    def clear()
    def show()
```

**Design pattern:**
- LED group abstraction (hides physical mapping)
- Non-blocking animations (duration control via parameters)
- Thread-safe (important for multi-threading)

### Deep Sleep & Wake

```python
# Setup wake pin
esp32.wake_on_ext1(
    pins=(Pin(MOTION_PIN),), 
    level=esp32.WAKEUP_ANY_HIGH
)

# Enter deep sleep
machine.deepsleep()

# On deep sleep wake:
# - ESP32 does complete RESET
# - main.py restarts from beginning
# - Non-persistent state (RAM cleared)
```

**Wake flow:**

```
MG24 detects movement
    │
    └─► GPIO8 = HIGH (200ms pulse)
         │
         └─► ESP32 wake
              │
              └─► Boot sequence
                   │
                   └─► main.py restart
                        │
                        └─► alive_pin.on()
                             │
                             └─► Animation started
```

## 🏠 ESPHome Version

### Event-Driven Architecture

ESPHome uses a **component** and **automation** based architecture.

```yaml
# Conceptual structure

esphome:
  on_boot: [actions]

binary_sensor:        # Input events
  on_press: [actions]
  on_release: [actions]

light:                # Output control
  effects: [...]

interval:             # Periodic tasks
  - interval: 1s
    then: [actions]

script:               # Reusable actions
  - id: script_name
    then: [actions]
```

### File: morphball.yaml

**Main sections:**

#### 1. Base Configuration

```yaml
substitutions:
  device_name: morphball
  friendly_name: "Metroid Morph Ball"

esp32:
  board: esp32-s3-devkitc-1
  framework:
    type: arduino

wifi:
  ssid: !secret wifi_ssid
  password: !secret wifi_password
```

#### 2. GPIO Setup

```yaml
# Output ALIVE
output:
  - platform: gpio
    pin: GPIO7
    id: alive_output

# Input MOTION
binary_sensor:
  - platform: gpio
    pin: GPIO8
    id: motion_sensor
    on_press:
      - script.execute: reset_sleep_timer
      - if: [wake logic]
```

#### 3. LED Control

```yaml
light:
  - platform: neopixelbus
    pin: GPIO18
    num_leds: 32
    id: morphball_light
    effects:
      - pulse:
          name: "Pulse"
      - addressable_lambda:
          name: "Custom"
          lambda: |-
            // C++ code here
```

**Lambda Effects - Detail:**

```cpp
// Lambda effect with direct LED access

it[index] = Color(R, G, B);

// Static variables for persistent state
static float brightness = 0.5;
static uint32_t last_update = 0;

// Logic
if (millis() - last_update > interval) {
    // Update colors
}
```

#### 4. Sleep Management

```yaml
globals:
  - id: last_motion_time
    type: uint32_t
  - id: sleep_mode_enabled
    type: bool

interval:
  - interval: 1s
    then:
      - if:
          condition:
            lambda: 'return check_timeout();'
          then:
            - light.turn_off
            - delay
            - deep_sleep.enter
```

#### 5. Home Assistant Integration

```yaml
api:
  encryption:
    key: !secret api_key

# Automatically exposed entities:
# - light.morphball_light
# - select.morphball_effect
# - number.morphball_sleep_timeout
# - binary_sensor.morphball_motion
# - sensor.morphball_wifi_signal
```

### OTA Updates

```yaml
ota:
  platform: esphome
  password: !secret ota_password

# Workflow:
# 1. esphome run morphball.yaml --device morphball.local
# 2. Compile new firmware
# 3. Upload via WiFi (no cable!)
# 4. Auto-reboot
```

## 🤖 MG24 - Motion Detection

### File: mg24_imu.ino

**Architecture:**

```cpp
// Setup
void setup() {
    pinMode(PIN_ALIVE, INPUT);
    pinMode(PIN_MOTION_OUT, OUTPUT);
    IMU.begin();
}

// Loop
void loop() {
    // 1. Read ESP32 status
    check_alive_signal();
    
    // 2. Read IMU
    aX = IMU.readFloatAccelX();
    aY = IMU.readFloatAccelY();
    aZ = IMU.readFloatAccelZ();
    
    // 3. Calculate magnitude
    aSum = abs(aX) + abs(aY) + abs(aZ);
    
    // 4. Threshold check
    if (aSum >= 2.5) {
        pulse_motion_pin();
    }
    
    delay(50);  // 20 Hz polling
}
```

**Detection Algorithm:**

```cpp
// Sum of absolute accelerations
float aSum = fabs(aX) + fabs(aY) + fabs(aZ);

// Static threshold
const float threshold = 2.5;  // G

// Temporal debouncing
static unsigned long lastMove = 0;
if (millis() - lastMove > 200) {  // Min 200ms between pulses
    digitalWrite(PIN_MOTION_OUT, HIGH);
    lastMove = millis();
}
```

**Possible Improvements:**

```cpp
// 1. Gesture recognition
enum Gesture {
    SHAKE,      // Rapid oscillation
    ROLL,       // Continuous rotation
    TILT,       // Static inclination
    TAP,        // Single hit
    DOUBLE_TAP  // Double hit
};

// 2. Adaptive threshold
float adaptive_threshold = 
    baseline_noise * 1.5 + offset;

// 3. I2C/UART communication instead of GPIO
// Send gesture type + intensity
```

## 🔄 Inter-MCU Communication

### Current GPIO Protocol

**ALIVE Signal (ESP32 → MG24):**

```
HIGH (3.3V)
  │     ┌───────────────────────┐
  │     │  Animations active    │
  │     │  MG24 normal polling  │
  │     └───────────────────────┘
  │
  └─► LOW (0V)
        │  ESP32 in deep sleep
        │  MG24 can reduce polling
        │  or go low power
        └───────────────────────┘
```

**MOTION Signal (MG24 → ESP32):**

```
Movement detected
  │
  ├─► Pulse HIGH (200ms)
  │    │
  │    └─► ESP32 wake (if in deep sleep)
  │         or reset timeout (if active)
  │
  └─► Return LOW
```

## 📊 Performance & Optimization

### Timing Analysis

**MicroPython:**
```
Animation frame time: ~20-50ms
Thread context switch: ~1-5ms
GPIO interrupt latency: <1ms
Deep sleep current: ~10µA
Wake time: ~100-300ms
```

**ESPHome:**
```
Effect update: 16-50ms (configurable)
API response: <100ms (LAN)
OTA update: ~30-60s
Component loop: 16ms (60 Hz)
```

### Memory Usage

**MicroPython ESP32-S3:**
```
Firmware: ~1.5MB flash
User code: ~50KB
Runtime RAM: ~100KB
Free heap: ~150KB
```

**ESPHome ESP32-S3:**
```
Firmware: ~2MB flash
Embedded config: ~10KB
Runtime: ~150KB
OTA partition: ~2MB
```

## 🧪 Testing & Debug

### MicroPython REPL

```python
# Connect via USB
screen /dev/ttyUSB0 115200

# Interactive test
>>> from ledstrip import LEDStrip
>>> leds = LEDStrip(18, 32, GROUPS)
>>> leds.set_group_color(0, (255, 0, 0))
>>> leds.show()
```

### ESPHome Logs

```bash
# Live monitor
esphome logs morphball.yaml

# Log levels
logger:
  level: DEBUG  # VERBOSE, DEBUG, INFO, WARN, ERROR
  
# Custom log
ESP_LOGD("tag", "Motion: %d", value);
```

## 📚 API Reference

### MicroPython LEDStrip API

```python
class LEDStrip:
    def __init__(self, pin: int, num_leds: int, 
                 groups: dict)
    
    def set_group_color(self, group_id: int, 
                       color: tuple[int, int, int])
    
    def pulse(self, duration: float = 1.0)
    
    def fade_in(self, duration: float = 1.0, 
                group_id: int = None)
    
    def fade_out(self, duration: float = 1.0, 
                 group_id: int = None)
    
    def clear(self, group_id: int = None)
    
    def show(self)
```

### ESPHome Services

```yaml
# Callable from HA automations

service: light.turn_on
target:
  entity_id: light.morphball_light
data:
  effect: "Rainbow"
  brightness: 200

service: select.select_option
target:
  entity_id: select.morphball_effect
data:
  option: "Pulse"
```

## 🔗 External References

- [MicroPython Docs](https://docs.micropython.org/)
- [ESPHome Docs](https://esphome.io/)
- [NeoPixel Guide](https://learn.adafruit.com/adafruit-neopixel-uberguide)
- [ESP32-S3 Technical Reference](https://www.espressif.com/sites/default/files/documentation/esp32-s3_technical_reference_manual_en.pdf)

---

**Last updated:** April 2026

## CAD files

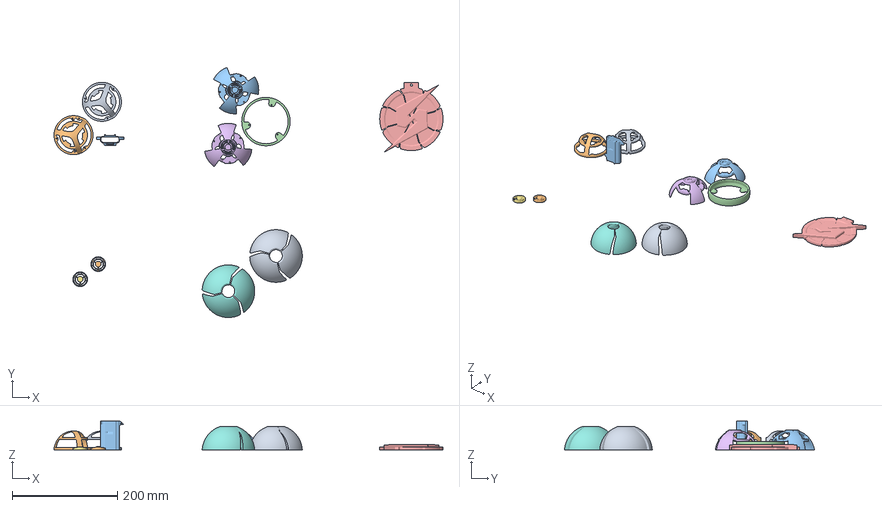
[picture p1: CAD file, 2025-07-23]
3D model/MorphBall.3mf
737.8 x 474.3 x 55.0 mm
BTM_Skeleton
TOP_Skeleton
CTR_Skeleton
InnerSphere TOP_CTR
Logo_metroid_prime_original_fixed.stl
BTM_InnerSphere
Core_Grill.stl x 2
Outer_Sphere_-_2.stl
Outer_Sphere_-_1.stl
TOP_InnerSphere

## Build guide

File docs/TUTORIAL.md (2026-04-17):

# 🛠️ Tutorial Completo - Build Your Morph Ball

Guida passo-passo dalla stampa 3D al primo avvio.

## 📋 Prerequisiti

### Cosa Ti Serve

**Hardware:**
- [ ] Stampante 3D (volume min: 150x150x150mm)
- [ ] Saldatore + stagno
- [ ] Multimetro
- [ ] Pinze, tronchesine
- [ ] Cacciaviti precisione
- [ ] Hot glue gun (opzionale)

**Software:**
- [ ] Slicer 3D (PrusaSlicer / Cura)
- [ ] Python 3.7+ (per MicroPython) o ESPHome
- [ ] Arduino IDE (per MG24)
- [ ] Driver USB-Serial (CP2102/CH340)
- [ ] Git (per clonare repo)

**Skill Level:**
- 🟢 Stampa 3D: Beginner
- 🟡 Elettronica: Intermediate
- 🟡 Programmazione: Intermediate
- 🟢 Assembly: Beginner

## 📦 Fase 1: Preparazione

### 1.1 Ordinare i Componenti

Segui la [BOM completa](HARDWARE.md#bill-of-materials-bom) e ordina tutto.

**Store consigliati:**
- **AliExpress**: ESP32-S3, MG24, LED strip, batterie
- **Amazon**: Cavi, connettori, tools
- **LCSC/DigiKey**: Componenti specifici (condensatori, etc.)

**Tempo:** 1-3 settimane per spedizioni

### 1.2 Clonare il Repository

```bash
git clone https://github.com/wizwally/morphball.git
cd morphball
```

### 1.3 Studiare la Documentazione

Leggi:
- [ ] [HARDWARE.md](HARDWARE.md) - Schema circuitale
- [ ] [SOFTWARE.md](SOFTWARE.md) - Architettura software
- [ ] [ESPHome/README.md](../ESPHome/README.md) - Se usi ESPHome

## 🖨️ Fase 2: Stampa 3D

### 2.1 Preparazione Modello

```bash
# Apri il modello 3D
cd "3D model"
# Importa MorphBall.3mf nel tuo slicer
```

### 2.2 Settings Stampa

**Materiale Consigliato:** PETG trasparente

**Profile:**
```
Layer Height: 0.2mm
Wall Thickness: 1.2mm (3 perimetri)
Infill: 15-20% (Gyroid)
Supports: SI (generare automaticamente)
Brim/Raft: NO (se bed leveling ok)
Temperature: 240°C (PETG)
Bed Temp: 80°C
Speed: 50mm/s
Retraction: 2mm @ 40mm/s
```

**Note importanti:**
- 🔴 **Supporti essenziali** per LED mounting holes
- 🟡 **Prima layer critica** - verifica adesione
- 🟢 **Z-seam**: posiziona sul retro per estetica

### 2.3 Post-Processing

```bash
# Dopo stampa:
1. Rimuovi supporti con cura (pinze)
2. Sbavatura con cutter
3. Leviga superfici con carta vetro 400-800
4. (Opzionale) Acetone vapor per smoothing PETG
```

**Tempo stampa:** 8-12 ore (dipende da dimensioni)

## 🔌 Fase 3: Elettronica

### 3.1 Test Componenti Individuali

Prima di saldare, **testa tutto separatamente!**

#### Test ESP32-S3

```bash
# Installa esptool
pip install esptool

# Test connessione
esptool.py --port /dev/ttyUSB0 chip_id

# Output atteso:
# Chip is ESP32-S3 (revision X)
```

#### Test LED Strip

```python
# Test con Arduino/ESP32 base
#include <Adafruit_NeoPixel.h>

Adafruit_NeoPixel strip(32, 18, NEO_GRB + NEO_KHZ800);

void setup() {
  strip.begin();
  strip.show();
}

void loop() {
  strip.fill(strip.Color(0, 255, 30));  // Verde
  strip.show();
  delay(1000);
}
```

✅ Tutti i 32 LED devono accendersi verde

#### Test MG24 IMU

```cpp
// Sketch di test LSM6DS3
#include <LSM6DS3.h>
#include <Wire.h>

LSM6DS3 IMU(I2C_MODE, 0x6A);

void setup() {
  Serial.begin(115200);
  IMU.begin();
}

void loop() {
  float aX = IMU.readFloatAccelX();
  Serial.print("X: "); Serial.println(aX);
  delay(100);
}
```

✅ Valori X ~0.0 fermo, cambiano se muovi la board

### 3.2 Saldature

**⚠️ IMPORTANTE: Testa TUTTO prima di saldare definitivamente!**

#### Ordine Saldature

1. **ESP32 ↔ MG24 Stack**

```
           MG24 (sopra)
            ║ ║ ║ ║
      ┌─────╨─╨─╨─╨──────┐
      │ D5 D4 3V3 GND     │
      │                   │
      │                   │
      └─────┬─┬─┬─┬───────┘
            ║ ║ ║ ║
       ESP32 (sotto)
```

Salda:
- MG24 D5 → ESP32 GPIO7
- MG24 D4 → ESP32 GPIO8  
- MG24 3V3 → ESP32 3V3
- MG24 GND → ESP32 GND

**Tecnica:**
- Fili corti (<3cm)
- 28-30 AWG silicone
- Colori: Rosso=3V3, Nero=GND, Giallo=D5, Verde=D4

2. **LED Strip → ESP32**

```
LED Strip          ESP32
DIN  ─────────────► GPIO18 (+ R 330Ω opzionale)
5V   ─────────────► 5V (o batteria+)
GND  ─────────────► GND
```

3. **Batteria + Circuito Alimentazione**

```
Batteria 3.7V LiPo
    ├─ (+) ─► Switch ─► TP4056 IN+ ─► 5V (LED + ESP32)
    └─ (-) ─────────────► TP4056 IN- ─► GND
                              │
                          USB charging
```

**⚠️ Attenzione Polarità!**
- Rosso = +
- Nero = -
- Inversione = 💥 componenti fritti

### 3.3 Isolamento

```
Dopo saldature:
1. Heat shrink su TUTTE le giunzioni
2. Verifica NO corti con multimetro
3. Test continuità con beeper
4. Hot glue su punti critici (anti-stress)
```

### 3.4 Test Assembly Elettronico

**Prima di chiudere nel guscio:**

```bash
# Power up test
1. Collega batteria
2. Accendi switch
3. Verifica:
   ✓ ESP32 LED status lampeggia
   ✓ MG24 LED (se presente) acceso
   ✓ LED strip verde (animazione base)
   ✓ NO fumo! 😅

# Motion test
4. Muovi delicatamente
5. Verifica:
   ✓ LED reagiscono (o serial monitor mostra "Motion")
   ✓ Animazioni continuano
```

## 💻 Fase 4: Software

### Opzione A: MicroPython (Standalone)

#### 4.1 Flash MicroPython

```bash
# Download firmware
wget https://micropython.org/download/esp32s3/

# Flash
esptool.py --chip esp32s3 --port /dev/ttyUSB0 erase_flash

esptool.py --chip esp32s3 --port /dev/ttyUSB0 \
  write_flash -z 0x0 esp32s3-20231005-v1.21.0.bin
```

#### 4.2 Upload Code

```bash
# Installa mpremote
pip install mpremote

# Upload files
cd ESP32
mpremote connect /dev/ttyUSB0 cp main.py :
mpremote connect /dev/ttyUSB0 cp ledstrip.py :
mpremote connect /dev/ttyUSB0 cp -r animations :
```

#### 4.3 Test

```bash
# REPL
mpremote connect /dev/ttyUSB0

>>> import main
# LED dovrebbero accendersi!
```

#### 4.4 Flash MG24

```bash
# Arduino IDE
1. Installa board: Seeed XIAO SAMD
2. Apri: MG24/mg24_imu.ino
3. Seleziona: Tools > Board > XIAO MG24
4. Seleziona: Tools > Port > /dev/ttyUSB1
5. Upload (Ctrl+U)

# Verifica serial monitor:
✅ IMU pronta — lettura accelerazioni
```

### Opzione B: ESPHome (Home Assistant)

#### 4.1 Setup ESPHome

```bash
# Installa
pip install esphome

# O usa HA addon
```

#### 4.2 Config Secrets

```bash
cd ESPHome
cp secrets.yaml.example secrets.yaml
nano secrets.yaml

# Compila:
wifi_ssid: "TuoWiFi"
wifi_password: "TuaPassword"
api_key: "<genera con: openssl rand -base64 32>"
```

#### 4.3 Compile & Flash

```bash
# Prima volta (via USB)
esphome run morphball.yaml

# Seleziona la porta seriale
# Attendi compilazione (~5 min prima volta)
# Flash automatico
```

#### 4.4 Aggiungi a Home Assistant

```
1. Impostazioni > Dispositivi e servizi
2. ESPHome > Configura
3. Host: morphball.local
4. Encryption key: <dalla secrets.yaml>
5. Fatto! 🎉
```

#### 4.5 Lovelace Card

```bash
# Copia card config
cat lovelace-card-simple.yaml

# Incolla in:
# Dashboard > Edit > Add Card > Manual
```

## 🔧 Fase 5: Assembly Finale

### 5.1 Preparazione Guscio

```bash
1. Pulisci interno con alcool isopropilico
2. Rimuovi polvere da stampa
3. Test fit componenti (NO glue ancora!)
4. Segna posizioni LED con marker
```

### 5.2 Installazione LED

```
LED Strip 32 LED disposizione:

    Top view (schematico)
    
      0           19
        1  [ESP]  18
    31    2    17   20
          3  16
    26  ...    ... 21
          14 4
    25    13   5   22
        12     6
      11       7  23
        10   8
           9       24
```

**Procedura:**
1. Taglia strip a misura (conserva connettori!)
2. Curva delicatamente (raggio min 2cm)
3. Fissa con hot glue ogni 8-10 LED
4. Routing DIN cable pulito verso ESP32

### 5.3 Montaggio Elettronica

```
Layout interno (sezione):

[Guscio superiore]
    │
    ├─ LED ring (incollati)
    │
[Shelf 3D print]
    │
    ├─ ESP32 + MG24 stack (viti M2)
    │
    ├─ Switch (snap fit o glue)
    │
[Shelf inferiore]
    │
    └─ Batteria (velcro o foam double-side)
```

**Ordine montaggio:**
1. LED strip (già fatto)
2. ESP32+MG24 stack con viti M2
3. Routing cavi (usa cable ties mini)
4. Switch nel foro dedicato
5. Batteria nell'alloggiamento
6. Verifica tutto si muove senza tirare cavi

### 5.4 Test Pre-Chiusura

```bash
✓ Power on
✓ LED check (tutti i 32)
✓ Motion test (muovi la ball)
✓ Serial monitor OK
✓ WiFi connect (se ESPHome)
✓ Home Assistant entity visible
```

### 5.5 Chiusura Finale

```
1. Allinea guscio superiore + inferiore
2. Viti M2 x 4-6 nei fori previsti
   
   ┌─────────────┐
   │      ●      │  ← Vite
   │   ┌───┐    │
   │ ● │   │ ●  │
   │   └───┘    │
   │      ●      │
   └─────────────┘

3. Serraggio graduale (no overtightening!)
4. Test finale rotazione/shake
5. Se tutto OK: applica O-ring (opzionale)
```

## 🎮 Fase 6: Testing & Calibrazione

### 6.1 Test Movimento

```bash
Test checklist:

□ Shake delicato → LED reagiscono
□ Roll continuo → Animazioni fluide
□ Fermo 20s → Standby (core only)
□ Fermo 40s → Deep sleep (tutto off)
□ Nuovo shake → Wake immediato
□ Nessun rumore meccanico interno
```

### 6.2 Calibrazione IMU

Se motion detection troppo sensibile/insensibile:

```cpp
// MG24/mg24_imu.ino

// Modifica questa linea:
const float accelerationThreshold = 2.5;  // Default

// Valori tipici:
// 1.5 = Molto sensibile (anche respiro)
// 2.5 = Medio (default)
// 4.0 = Poco sensibile (serve shake deciso)
```

Re-upload e testa!

### 6.3 Tuning Animazioni

**MicroPython:**

```python
# ESP32/main.py

# Timeout sleep
SLEEP_TIMEOUT_MS = 20_000   # Aumenta se troppo veloce
STANDBY_WAIT_MS  = 20_000   # Idem

# Colori gruppi
leds.set_group_color(0, (R, G, B))  # Modifica colori
```

**ESPHome:**

```yaml
# ESPHome/morphball.yaml

# Timeout via HA dashboard (dinamico!)
number:
  - platform: template
    name: "Sleep Timeout"
    initial_value: 20  # Secondi
```

### 6.4 Test Autonomia

```bash
Batteria test (750mAh esempio):

1. Carica completa (LED TP4056 verde)
2. Uso normale (shake ogni ~30s)
3. Monitor tempo fino a spegnimento

Autonomia attesa: ~45-90 minuti

Se troppo breve:
- ✓ Verifica brightness LED (riduci a 50-70%)
- ✓ Controlla consumi parassiti (multimetro)
- ✓ Batteria più grande (1000mAh+)
```

## 🎨 Fase 7: Customizzazione

### 7.1 Effetti LED Custom

**ESPHome Lambda:**

```yaml
- addressable_lambda:
    name: "My Custom Effect"
    update_interval: 50ms
    lambda: |-
      static float hue = 0;
      for (int i = 0; i < it.size(); i++) {
        it[i] = Color::from_hsv((hue + i * 10), 1.0, 1.0);
      }
      hue += 1;
      if (hue > 360) hue = 0;
```

**MicroPython:**

```python
# ESP32/animations/rainbow.py
class RainbowAnimation(Animation):
    def run(self, speed=10):
        for hue in range(360):
            rgb = hsv_to_rgb(hue / 360.0, 1.0, 1.0)
            self.ledstrip.np.fill(rgb)
            self.ledstrip.show()
            time.sleep_ms(speed)
```

### 7.2 Automazioni HA

```yaml
# configuration.yaml o automations.yaml

automation:
  # Al tramonto → Rainbow
  - alias: "Morphball Sunset Rainbow"
    trigger:
      platform: sun
      event: sunset
    action:
      service: select.select_option
      target:
        entity_id: select.metroid_morph_ball_effect
      data:
        option: "Rainbow"

  # Su notifica → Strobe rosso
  - alias: "Morphball Alert Flash"
    trigger:
      platform: state
      entity_id: binary_sensor.front_door
      to: 'on'
    action:
      - service: light.turn_on
        target:
          entity_id: light.metroid_morph_ball_leds
        data:
          rgb_color: [255, 0, 0]
          effect: "Strobe"
```

### 7.3 Voice Control

**Google Assistant:**

```yaml
# Esponi entità in HA
google_assistant:
  entity_config:
    light.metroid_morph_ball_leds:
      name: "Morph Ball"
      room: Living Room

# Comandi vocali:
"Ok Google, accendi Morph Ball"
"Ok Google, imposta Morph Ball su verde"
"Ok Google, Morph Ball effetto rainbow"
```

## 🐛 Troubleshooting Common Issues

### Issue: LED non si accendono

**Debug:**
```bash
1. Verifica alimentazione: 
   multimetro su 5V rail → deve essere ~5V

2. Verifica DIN signal:
   oscilloscopio/logic analyzer → deve esserci data

3. Test singolo LED:
   scollega strip, prova con 1 LED solo

4. Verifica library:
   MicroPython: from neopixel import NeoPixel
   ESPHome: platform: neopixelbus
```

**Fix comuni:**
- ❌ DIN disconnesso → risalda
- ❌ 5V troppo basso (<4.5V) → batteria scarica o regolatore fail
- ❌ LED strip invertito → DIN va sul primo LED del strip!
- ❌ DOUT del primo LED rotto → salta primo LED, usa il secondo

### Issue: Motion non rilevato

**Debug:**
```cpp
// MG24 serial monitor
void loop() {
  float aSum = fabs(aX) + fabs(aY) + fabs(aZ);
  Serial.print("Accel: "); Serial.println(aSum);
  // Deve cambiare quando muovi!
}
```

**Fix comuni:**
- ❌ Threshold troppo alto → riduci a 1.5
- ❌ GPIO8 non connesso → verifica continuità
- ❌ IMU not inizializzato → check I2C address (0x6A o 0x6B?)

### Issue: Deep sleep non funziona

**Debug:**
```python
# main.py
print(f"Last motion: {time.ticks_diff(time.ticks_ms(), last_motion_time)}ms ago")
print(f"Active: {active}")
```

**Fix comuni:**
- ❌ Motion continuo impedisce sleep → normale! Aspetta 20s fermo
- ❌ Timeout troppo breve → aumenta SLEEP_TIMEOUT_MS
- ❌ Wake pin mal configurato → check `esp32.wake_on_ext1()`

### Issue: WiFi non si connette (ESPHome)

**Debug:**
```bash
esphome logs morphball.yaml

# Cerca linee tipo:
[W][wifi:xxx] No WiFi SSID set!
[E][wifi:xxx] WiFi connection failed!
```

**Fix comuni:**
- ❌ SSID/password errati in secrets.yaml
- ❌ WiFi 5GHz → ESP32 supporta solo 2.4GHz!
- ❌ Segnale debole → antenna ESP32 posizionata male
- ❌ MAC filtering router → aggiungi ESP32 MAC

## 📸 Showcase & Share

### 📷 Photo Tips

```
Best angles:
1. Top-down (mostra LED pattern)
2. Side 45° (mostra forma sferica)
3. Dark room + long exposure (LED trails!)
4. Slow-motion video (LED effects)
```

### 🎥 Video Demo

Mostra:
- ✨ LED effects showcase (tutti i 11)
- 🏃 Motion detection (shake test)
- 💤 Sleep/wake cycle
- 🏠 Home Assistant control

### 🌐 Community

Condividi il tuo build!

- **Reddit**: r/3Dprinting, r/ESP32, r/homeassistant
- **Discord**: ESPHome, Home Assistant
- **YouTube**: Tutorial + showcase
- **GitHub**: Issues & Pull Requests su questo repo!

---

## 🎉 Congratulazioni!

Hai completato la tua Metroid Morph Ball! 🔮

**Prossimi step:**
- [ ] Fine-tuning animazioni
- [ ] Setup automazioni HA
- [ ] Considera PCB custom per v2.0
- [ ] Stampa altre ball e fai effetti sincronizzati!

**Enjoy your build!** 🎮

---

**Build time totale stimato:** 2-3 giorni (non consecutivi)

- Stampa 3D: 8-12h
- Elettronica: 3-4h
- Software: 1-2h
- Assembly: 2-3h
- Testing/tuning: 2-4h

**Ultimo aggiornamento:** Aprile 2026

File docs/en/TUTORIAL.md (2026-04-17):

# 🛠️ Complete Tutorial - Build Your Morph Ball

Step-by-step guide from 3D printing to first boot.

## 📋 Prerequisites

### What You Need

**Hardware:**
- [ ] 3D Printer (min volume: 150x150x150mm)
- [ ] Soldering iron + solder
- [ ] Multimeter
- [ ] Pliers, wire cutters
- [ ] Precision screwdrivers
- [ ] Hot glue gun (optional)

**Software:**
- [ ] 3D Slicer (PrusaSlicer / Cura)
- [ ] Python 3.7+ (for MicroPython) or ESPHome
- [ ] Arduino IDE (for MG24)
- [ ] USB-Serial drivers (CP2102/CH340)
- [ ] Git (to clone repo)

**Skill Level:**
- 🟢 3D Printing: Beginner
- 🟡 Electronics: Intermediate
- 🟡 Programming: Intermediate
- 🟢 Assembly: Beginner

## 🖨️ Phase 2: 3D Printing

### 2.1 Model Preparation

```bash
# Open the 3D model
cd "3D model"
# Import MorphBall.3mf into your slicer
```

### 2.2 Print Settings

**Recommended Material:** Transparent PETG

**Profile:**
```
Layer Height: 0.2mm
Wall Thickness: 1.2mm (3 perimeters)
Infill: 15-20% (Gyroid)
Supports: YES (auto-generate)
Brim/Raft: NO (if bed leveling ok)
Temperature: 240°C (PETG)
Bed Temp: 80°C
Speed: 50mm/s
Retraction: 2mm @ 40mm/s
```

**Important notes:**
- 🔴 **Supports essential** for LED mounting holes
- 🟡 **First layer critical** - verify adhesion
- 🟢 **Z-seam**: position at back for aesthetics

**Print time:** 8-12 hours (depends on size)

## 🔌 Phase 3: Electronics

### 3.1 Test Individual Components

Before soldering, **test everything separately!**

#### Test ESP32-S3

```bash
# Install esptool
pip install esptool

# Test connection
esptool.py --port /dev/ttyUSB0 chip_id

# Expected output:
# Chip is ESP32-S3 (revision X)
```

#### Test LED Strip

```python
# Test with Arduino/base ESP32
#include <Adafruit_NeoPixel.h>

Adafruit_NeoPixel strip(32, 18, NEO_GRB + NEO_KHZ800);

void setup() {
  strip.begin();
  strip.show();
}

void loop() {
  strip.fill(strip.Color(0, 255, 30));  // Green
  strip.show();
  delay(1000);
}
```

✅ All 32 LEDs should light up green

### 3.2 Soldering

**⚠️ IMPORTANT: Test EVERYTHING before permanent soldering!**

#### Soldering Order

1. **ESP32 ↔ MG24 Stack**

Solder:
- MG24 D5 → ESP32 GPIO7
- MG24 D4 → ESP32 GPIO8  
- MG24 3V3 → ESP32 3V3
- MG24 GND → ESP32 GND

**Technique:**
- Short wires (<3cm)
- 28-30 AWG silicone
- Colors: Red=3V3, Black=GND, Yellow=D5, Green=D4

2. **LED Strip → ESP32**

```
LED Strip          ESP32
DIN  ─────────────► GPIO18 (+ 330Ω R optional)
5V   ─────────────► 5V (or battery+)
GND  ─────────────► GND
```

3. **Battery + Power Circuit**

```
3.7V LiPo Battery
    ├─ (+) ─► Switch ─► TP4056 IN+ ─► 5V (LEDs + ESP32)
    └─ (-) ─────────────► TP4056 IN- ─► GND
                              │
                          USB charging
```

**⚠️ Polarity Warning!**
- Red = +
- Black = -
- Reversal = 💥 fried components

### 3.3 Insulation

```
After soldering:
1. Heat shrink on ALL connections
2. Verify NO shorts with multimeter
3. Test continuity with beeper
4. Hot glue on critical points (stress relief)
```

## 💻 Phase 4: Software

### Option A: MicroPython (Standalone)

#### 4.1 Flash MicroPython

```bash
# Download firmware
wget https://micropython.org/download/esp32s3/

# Flash
esptool.py --chip esp32s3 --port /dev/ttyUSB0 erase_flash

esptool.py --chip esp32s3 --port /dev/ttyUSB0 \
  write_flash -z 0x0 esp32s3-micropython.bin
```

#### 4.2 Upload Code

```bash
# Install mpremote
pip install mpremote

# Upload files
cd ESP32
mpremote connect /dev/ttyUSB0 cp main.py :
mpremote connect /dev/ttyUSB0 cp ledstrip.py :
mpremote connect /dev/ttyUSB0 cp -r animations :
```

#### 4.3 Flash MG24

```bash
# Arduino IDE
1. Install board: Seeed XIAO SAMD
2. Open: MG24/mg24_imu.ino
3. Select: Tools > Board > XIAO MG24
4. Select: Tools > Port > /dev/ttyUSB1
5. Upload (Ctrl+U)

# Verify serial monitor:
✅ IMU ready — reading accelerations
```

### Option B: ESPHome (Home Assistant)

#### 4.1 Setup ESPHome

```bash
# Install
pip install esphome

# Or use HA addon
```

#### 4.2 Config Secrets

```bash
cd ESPHome
cp secrets.yaml.example secrets.yaml
nano secrets.yaml

# Fill:
wifi_ssid: "YourWiFi"
wifi_password: "YourPassword"
api_key: "<generate with: openssl rand -base64 32>"
```

#### 4.3 Compile & Flash

```bash
# First time (via USB)
esphome run morphball.yaml

# Select serial port
# Wait for compilation (~5 min first time)
# Auto-flash
```

#### 4.4 Add to Home Assistant

```
1. Settings > Devices & Services
2. ESPHome > Configure
3. Host: morphball.local
4. Encryption key: <from secrets.yaml>
5. Done! 🎉
```

## 🔧 Phase 5: Final Assembly

### 5.1 Shell Preparation

```bash
1. Clean inside with isopropyl alcohol
2. Remove print dust
3. Test fit components (NO glue yet!)
4. Mark LED positions with marker
```

### 5.2 LED Installation

**Procedure:**
1. Cut strip to size (preserve connectors!)
2. Bend gently (min radius 2cm)
3. Secure with hot glue every 8-10 LEDs
4. Clean DIN cable routing to ESP32

### 5.3 Electronics Mounting

```
Internal layout (section):

[Upper shell]
    │
    ├─ LED ring (glued)
    │
[3D print shelf]
    │
    ├─ ESP32 + MG24 stack (M2 screws)
    │
    ├─ Switch (snap fit or glue)
    │
[Lower shelf]
    │
    └─ Battery (velcro or foam double-side)
```

### 5.4 Pre-Closure Test

```bash
✓ Power on
✓ LED check (all 32)
✓ Motion test (shake the ball)
✓ Serial monitor OK
✓ WiFi connect (if ESPHome)
✓ Home Assistant entity visible
```

### 5.5 Final Closure

```
1. Align upper + lower shell
2. M2 screws x 4-6 in provided holes
3. Gradual tightening (no overtightening!)
4. Final rotation/shake test
5. If all OK: apply O-ring (optional)
```

## 🎮 Phase 6: Testing & Calibration

### 6.1 Movement Test

```bash
Test checklist:

□ Gentle shake → LEDs react
□ Continuous roll → Smooth animations
□ Stationary 20s → Standby (core only)
□ Stationary 40s → Deep sleep (all off)
□ New shake → Immediate wake
□ No internal mechanical noise
```

### 6.2 IMU Calibration

If motion detection too sensitive/insensitive:

```cpp
// MG24/mg24_imu.ino

// Modify this line:
const float accelerationThreshold = 2.5;  // Default

// Typical values:
// 1.5 = Very sensitive (even breathing)
// 2.5 = Medium (default)
// 4.0 = Less sensitive (needs firm shake)
```

Re-upload and test!

### 6.3 Animation Tuning

**MicroPython:**

```python
# ESP32/main.py

# Sleep timeout
SLEEP_TIMEOUT_MS = 20_000   # Increase if too fast
STANDBY_WAIT_MS  = 20_000   # Same

# Group colors
leds.set_group_color(0, (R, G, B))  # Modify colors
```

**ESPHome:**

```yaml
# ESPHome/morphball.yaml

# Timeout via HA dashboard (dynamic!)
number:
  - platform: template
    name: "Sleep Timeout"
    initial_value: 20  # Seconds
```

## 🎨 Phase 7: Customization

### 7.1 Custom LED Effects

**ESPHome Lambda:**

```yaml
- addressable_lambda:
    name: "My Custom Effect"
    update_interval: 50ms
    lambda: |-
      static float hue = 0;
      for (int i = 0; i < it.size(); i++) {
        it[i] = Color::from_hsv((hue + i * 10), 1.0, 1.0);
      }
      hue += 1;
      if (hue > 360) hue = 0;
```

### 7.2 HA Automations

```yaml
# configuration.yaml or automations.yaml

automation:
  # At sunset → Rainbow
  - alias: "Morphball Sunset Rainbow"
    trigger:
      platform: sun
      event: sunset
    action:
      service: select.select_option
      target:
        entity_id: select.metroid_morph_ball_effect
      data:
        option: "Rainbow"
```

## 🐛 Troubleshooting Common Issues

### Issue: LEDs don't light up

**Debug:**
```bash
1. Verify power: 
   multimeter on 5V rail → should be ~5V

2. Verify DIN signal:
   oscilloscope/logic analyzer → should have data

3. Test single LED:
   disconnect strip, try with 1 LED only
```

**Common fixes:**
- ❌ DIN disconnected → re-solder
- ❌ 5V too low (<4.5V) → dead battery or regulator fail
- ❌ LED strip reversed → DIN goes to first LED!
- ❌ First LED DOUT broken → skip first LED, use second

### Issue: Motion not detected

**Debug:**
```cpp
// MG24 serial monitor
void loop() {
  float aSum = fabs(aX) + fabs(aY) + fabs(aZ);
  Serial.print("Accel: "); Serial.println(aSum);
  // Should change when you move!
}
```

**Common fixes:**
- ❌ Threshold too high → reduce to 1.5
- ❌ GPIO8 not connected → verify continuity
- ❌ IMU not initialized → check I2C address (0x6A or 0x6B?)

## 🎉 Congratulations!

You've completed your Metroid Morph Ball! 🔮

**Next steps:**
- [ ] Fine-tune animations
- [ ] Setup HA automations
- [ ] Consider custom PCB for v2.0
- [ ] Print more balls and make synchronized effects!

**Enjoy your build!** 🎮

---

**Total build time estimate:** 2-3 days (non-consecutive)

- 3D printing: 8-12h
- Electronics: 3-4h
- Software: 1-2h
- Assembly: 2-3h
- Testing/tuning: 2-4h

**Last updated:** April 2026

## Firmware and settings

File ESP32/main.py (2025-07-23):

import esp32
import machine
import time
import _thread
from ledstrip import LEDStrip  # Assicurati di avere ledstrip.py caricato
from machine import Pin


# CONFIGURAZIONE
LED_PIN    = 18   # GPI18 → DIN strip WS2812
NUM_LEDS   = 32
MOTION_PIN = 8    # GPIO7 ← segnale da MG24
ALIVE_PIN  = 7    # GPIO8 → segnale animation on a MG24
 
SLEEP_TIMEOUT_MS = 20_000  # 30 secondi
STANDBY_WAIT_MS  = 20_000   # 30 secondi extra prima di deep sleep


# Gruppi LED
GROUPS = {
    0: [0, 19, 20, 25, 26, 31],
    1: [1, 2, 17, 18, 21, 22, 23, 24, 27, 28, 29, 30],
    2: list(range(3, 17))
}

# Stato condiviso
active = True
last_motion_time = time.ticks_ms()
anim_thread_started = False
 
# GPIO setup
alive_pin = machine.Pin(ALIVE_PIN, machine.Pin.OUT)
alive_pin.on()  # subito HIGH all'avvio

motion_pin = machine.Pin(MOTION_PIN, machine.Pin.IN)
esp32.wake_on_ext1(pins=(Pin(MOTION_PIN,),), level=esp32.WAKEUP_ANY_HIGH)

# LEDStrip init
leds = LEDStrip(LED_PIN, NUM_LEDS, GROUPS)

# ISR per impulsi da MG24
def motion_interrupt(pin):
    global last_motion_time, active, anim_thread_started
    last_motion_time = time.ticks_ms()
    if not active:
        print("📡 Movimento durante standby → riattivo animazione")
        active = True
        if not anim_thread_started:
            anim_thread_started = True
            _thread.start_new_thread(animation_loop, ())

motion_pin.irq(trigger=machine.Pin.IRQ_RISING, handler=motion_interrupt)

# Thread animazione LED
def animation_loop():
    global active, anim_thread_started
    print("Starting animation thread")
    
    # Colori iniziali
    leds.set_group_color(0, (0, 230, 100))  # Core grills
    leds.set_group_color(1, (0, 255, 30))   # Inner
    leds.set_group_color(2, (0, 255, 30))   # Ring
    
    while active:
        leds.pulse(duration=1)
    leds.clear()
    # Fade solo del gruppo 0
    leds.fade_in(duration = 1, group_id = 0)
    # Core grills soft standby
    anim_thread_started = False

# Thread monitor timeout → standby → deep sleep
def motion_monitor():
    global active
    print("Starting monitor thread")
    while True:
        delta = time.ticks_diff(time.ticks_ms(), last_motion_time)
        if delta > SLEEP_TIMEOUT_MS:
            print("🏁 Timeout: stop animazione, standby")
            active = False
            t0 = time.ticks_ms()
            while time.ticks_diff(time.ticks_ms(), t0) < STANDBY_WAIT_MS:
                if active:
                    print("🔄 Movimento durante standby → annullo sleep")
                    break
                time.sleep(0.5)
            if not active:
                print("💤 Deep sleep")
                alive_pin.off()
                leds.fade_out(duration = 1, group_id = 0)
                time.sleep_ms(100)  # tempo per MG24 di leggere LOW
                machine.deepsleep()
        time.sleep(0.5)

# Avvio thread
_thread.start_new_thread(animation_loop, ())
_thread.start_new_thread(motion_monitor, ())

# Loop principale
while True:
    time.sleep(1)

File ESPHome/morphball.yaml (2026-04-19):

substitutions:
  device_name: morphball
  friendly_name: "Metroid Morph Ball"
  
esphome:
  name: ${device_name}
  friendly_name: ${friendly_name}
  on_boot:
    priority: -100
    then:
      # All'avvio, segnala al MG24 che siamo vivi
      - output.turn_on: alive_output
      - light.turn_on: 
          id: morphball_light
          effect: "Pulse"

esp32:
  board: esp32-s3-devkitc-1
  framework:
    type: arduino

# WiFi e API
wifi:
  ssid: !secret wifi_ssid
  password: !secret wifi_password
  
  ap:
    ssid: "${device_name} Fallback"
    password: !secret ap_password

# Home Assistant API
api:
  encryption:
    key: !secret api_key

ota:
  - platform: esphome
    password: !secret ota_password

logger:
  level: INFO

# ==========================================
# GPIO CONFIGURATION
# ==========================================

# Pin ALIVE → MG24 (GPIO7)
output:
  - platform: gpio
    pin: GPIO7
    id: alive_output
    inverted: false

# Pin MOTION ← MG24 (GPIO8)  
binary_sensor:
  - platform: gpio
    pin: 
      number: GPIO8
      mode: INPUT
      inverted: false
    name: "${friendly_name} Motion"
    id: motion_sensor
    device_class: motion
    filters:
      - delayed_off: 200ms
    on_press:
      then:
        - logger.log: "📡 Movimento rilevato dal MG24"
        - script.execute: reset_sleep_timer
        - if:
            condition:
              lambda: 'return id(sleep_mode_enabled);'
            then:
              - if:
                  condition:
                    light.is_off: morphball_light
                  then:
                    - logger.log: "Wake from standby"
                    - light.turn_on: 
                        id: morphball_light
                        effect: !lambda 'return id(current_effect).state.c_str();'

# ==========================================
# LED STRIP WS2812B
# ==========================================

light:
  - platform: neopixelbus
    type: GRB
    variant: WS2812
    pin: GPIO18
    num_leds: 32
    name: "${friendly_name} LEDs"
    id: morphball_light
    restore_mode: ALWAYS_OFF
    default_transition_length: 500ms
    effects:
      # Pulse effect - classico
      - pulse:
          name: "Pulse"
          transition_length: 1s
          update_interval: 1s
          min_brightness: 30%
          max_brightness: 100%
      
      # Breathing - più lento e smooth
      - pulse:
          name: "Breathing"
          transition_length: 2s
          update_interval: 2s
          min_brightness: 10%
          max_brightness: 100%
      
      # Strobe - veloce
      - strobe:
          name: "Strobe"
          colors:
            - state: true
              brightness: 100%
              duration: 100ms
            - state: false
              duration: 100ms
      
      # Rainbow
      - addressable_rainbow:
          name: "Rainbow"
          speed: 10
          width: 32
      
      # Color wipe
      - addressable_color_wipe:
          name: "Color Wipe"
          colors:
            - red: 0%
              green: 90%
              blue: 39%
              num_leds: 32
            - red: 0%
              green: 100%
              blue: 12%
              num_leds: 32
          add_led_interval: 50ms
          reverse: false
      
      # Scan
      - addressable_scan:
          name: "Scan"
          move_interval: 50ms
          scan_width: 4
      
      # Twinkle
      - addressable_twinkle:
          name: "Twinkle"
          twinkle_probability: 5%
          progress_interval: 50ms
      
      # Fireworks
      - addressable_fireworks:
          name: "Fireworks"
          update_interval: 50ms
          spark_probability: 10%
          use_random_color: false
          fade_out_rate: 120
      
      # Flicker
      - addressable_flicker:
          name: "Flicker"
          update_interval: 16ms
          intensity: 5%
      
      # ==========================================
      # CUSTOM ANIMATIONS - From Original MicroPython Code
      # ==========================================
      
      # Pulse Sinusoidal - Original MicroPython version
      # Uses math.sin for smooth breathing on all groups
      - addressable_lambda:
          name: "Pulse Original"
          update_interval: 20ms
          lambda: |-
            // Gruppo 0: Core grills [0, 19, 20, 25, 26, 31]
            static int group0[] = {0, 19, 20, 25, 26, 31};
            // Gruppo 1: Inner [1, 2, 17, 18, 21, 22, 23, 24, 27, 28, 29, 30]
            static int group1[] = {1, 2, 17, 18, 21, 22, 23, 24, 27, 28, 29, 30};
            // Gruppo 2: Ring [3-16]
            
            static float phase = 0;
            static int direction = 1;
            const float speed = 2.0;  // Increment per frame
            const float brightness_max = 0.8;
            
            // Increment phase
            phase += direction * speed;
            
            // Bounce at limits
            if (phase >= 200) {
              direction = -1;
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

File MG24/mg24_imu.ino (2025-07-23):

#include <LSM6DS3.h>
#include <Wire.h>

// Pin definitions
#define PIN_ALIVE       D5   // ← segnale dallo ESP32 (HIGH = attivo)
#define PIN_MOTION_OUT  D4   // → va a GPIO13 ESP32 per wake/reset timeout

// Oggetto IMU
LSM6DS3 IMU(I2C_MODE, 0x6A);  // I2C device address 0x6A

// Variabili lettura IMU
float aX, aY, aZ;
const float accelerationThreshold = 2.5;  // soglia in G per "movimento"
int ESP_alive = 0;

void setup() {
  pinMode(PIN_ALIVE, INPUT);
  pinMode(PIN_MOTION_OUT, OUTPUT);
  digitalWrite(PIN_MOTION_OUT, LOW);

  Serial.begin(115200);
  while (!Serial);

  if (IMU.begin() != 0) {
    Serial.println("⚠️ IMU non trovata o errore inizializzazione");
  } else {
    Serial.println("✅ IMU pronta — lettura accelerazioni");
    Serial.println("aX,aY,aZ");
  }
}

void loop() {
  // Lettura stato attuale del pin alive da ESP32
  int _ESP_alive = digitalRead(PIN_ALIVE);
  if (_ESP_alive != ESP_alive) {
    ESP_alive = _ESP_alive;
    Serial.print("🔄 ESP Animation state: ");
    Serial.println(ESP_alive ? "ON" : "OFF");
  }

  // Lettura accelerometro
  aX = IMU.readFloatAccelX();
  aY = IMU.readFloatAccelY();
  aZ = IMU.readFloatAccelZ();

  float aSum = fabs(aX) + fabs(aY) + fabs(aZ);

  static unsigned long lastMove = 0;
  if (aSum >= accelerationThreshold) {
    if (millis() - lastMove > 200) {
      Serial.println("📡 Movimento → alza PIN su ESP32");
      digitalWrite(PIN_MOTION_OUT, HIGH);
      lastMove = millis();
    }
  } else {
    digitalWrite(PIN_MOTION_OUT, LOW);
  }

  delay(50);  // frequenza di aggiornamento IMU
}

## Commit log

2025-07-23 FirstCommit
    ESP32 basic implementation:
    - main.py supports movement detection trigger from MG24, deep sleep mgmt, LEDs animation class not integrated
    - animation class ready
    - pulse animation ready
    MG24 basic implementation ready:
    - movement detection
    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
    [MorphBall.3mf]
2026-04-17 Add ESPHome configuration for Home Assistant integration
    - Full ESPHome YAML config with 11 LED effects
    - Sleep management with configurable timeouts
    - Motion detection integration with MG24
    - Deep sleep support with GPIO wake
    - Lovelace dashboard cards (Mushroom + simple version)
    - Complete setup documentation in Italian
    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
2026-04-17 Add complete documentation
    - Comprehensive README with project overview and features
    - HARDWARE.md: Complete BOM, schematics, assembly guide
    - SOFTWARE.md: Architecture deep-dive for both MicroPython and ESPHome
    - TUTORIAL.md: Step-by-step build guide from 3D printing to final assembly
    - CONTRIBUTING.md: Guidelines for contributors
    - Updated main README with better structure and badges
2026-04-17 Add English documentation
    - Complete English translations of all documentation
    - docs/en/README.md: Project overview
    - docs/en/HARDWARE.md: BOM, schematics, assembly
    - docs/en/SOFTWARE.md: Architecture for MicroPython & ESPHome
    - docs/en/TUTORIAL.md: Complete build guide
    - docs/en/CONTRIBUTING.md: Contribution guidelines
    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
2026-04-17 Make English default language and add dual-MCU architecture rationale
    - README.md now in English by default
    - Added Italian README at docs/README_IT.md
    - Added 'Why Dual-MCU Architecture?' section explaining:
    * Power management optimization (~100µA standby vs ~5mA single-MCU)
    * Real-time performance with task separation
    * <50ms wake latency vs 100-500ms alternatives
    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
2026-04-17 Add original MicroPython custom animations to ESPHome
    - Pulse Original: Sinusoidal breathing with group-specific colors
    * Group 0 (core): Aqua green (0, 230, 100)
    * Group 1 (inner): Bright green (0, 255, 30)
    * Group 2 (ring): Bright green (0, 255, 30)
    * Uses sin² formula for smooth breathing effect
    - Rotation Original: Rotating gradient on Group 2 only
    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
2026-04-19 Fix GPIO8 pin conflict between binary_sensor and deep_sleep
    - Added allow_other_uses: true to GPIO8 binary_sensor
    - Allows pin to be used both as motion input and deep_sleep wakeup
    - Also added inverted: false for clarity
    [morphball.yaml]
2026-04-19 Fix deep_sleep config using esp32_ext1_wakeup instead of wakeup_pin
    - Changed from wakeup_pin to esp32_ext1_wakeup
    - Uses INPUT_PULLDOWN mode for GPIO8
    - mode: ANY_HIGH triggers wake on HIGH signal from MG24
    - This properly resolves pin conflict with binary_sensor
    [morphball.yaml]
2026-04-19 Disable deep_sleep temporarily to resolve GPIO8 pin conflict
    - Deep sleep commented out to avoid pin conflict with binary_sensor
    - GPIO8 can now be used solely for motion detection
    - Deep sleep can be re-enabled later with proper wakeup configuration
    - For now, ESP32 will stay in light sleep mode when idle (still low power)
    [morphball.yaml]
2026-04-19 Remove allow_other_uses from GPIO8 binary_sensor
    Since deep_sleep is disabled, allow_other_uses is not needed and causes validation error
    [morphball.yaml]
2026-04-22 Add MG24 UART pinout (D6/D7, D11/D12) and UART BACKLOG
    - Document D6/D7 (Serial1 TX/RX toward ESP32) and D11/D12 (SAMD11
    debug bridge, do not touch) in MG24 pinout across IT/EN HARDWARE.md
    and README.md
    - Add BACKLOG section in SOFTWARE.md: 4-byte frame protocol, Arduino
    encoder skeleton (sendGestureFrame), MicroPython decoder skeleton
    (read_gesture_frame + uart_monitor_loop), gesture→animation mapping

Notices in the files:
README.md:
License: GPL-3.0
